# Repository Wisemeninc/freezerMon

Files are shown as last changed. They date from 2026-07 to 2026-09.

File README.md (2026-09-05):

# freezerMon

Cellular monitoring for a mobile cooling unit. A LilyGO **[T-A7608E-H](https://lilygo.cc/products/t-a7608e-h)** (ESP32 + SIMCom A7608E-H LTE Cat-4) reads temperature, door, battery/power-source and GPS, and publishes JSON over **LTE → MQTT**. A self-hosted stack (**Mosquitto → Telegraf → InfluxDB → Grafana**) stores it, draws dashboards, and fires alerts.

```
[DS18B20 x2]──┐
[reed switch]─┤  T-A7608E-H  ──LTE──►  Mosquitto ──► Telegraf ──► InfluxDB ──► Grafana
[battery/VIN]─┘  (deep sleep,                        (MQTT)        (ingest)     (store)     (dash + alerts)
                  offline buffer, GPS)
```

## What the device reports

Two operating regimes: on **battery** the device deep-sleeps between reports (default 5 min; 1 min during alarm/door-open) and wakes instantly on door-open via interrupt. On **external power** it never sleeps — the LTE session stays up, the door is polled every 250 ms (instant alerts), and it reports every 2 min. Payload, retained on `freezer/<id>/telemetry`:

| field | meaning |
|---|---|
| `ts` | unix epoch (from cellular network clock) |
| `t_cab`, `t_amb` | DS18B20 cabinet / ambient °C (second probe optional) |
| `door` | 1 = open (also triggers an instant wake + publish via interrupt) |
| `ext_power` | 1 = running on external power, 0 = on battery |
| `vbat_mv`, `vsolar_mv` | battery / VIN-solar millivolts |
| `rssi_dbm` | LTE signal |
| `lat`, `lon` | GPS fix — **present only when a fix was obtained that wake** (attempted every Nth report to save power). A missing coordinate means "no fix", never a replayed old position; last-known location is whatever the DB holds. |
| `hdop`, `sats` | quality of that fix (horizontal dilution of precision; satellites in view summed over GPS/BeiDou/GLONASS/Galileo) — present with `lat`/`lon`. Fixes are gated: 3D with HDOP ≤ `GPS_MAX_HDOP` (2.5), and the lowest-HDOP sample of a `GPS_SETTLE_S` (10 s) dwell after the first good one; a window that never meets the gate publishes no coordinate. |
| `gps_last`, `gps_last_s`, `gps_last_sats`, `gps_last_svs`, `gps_last_hdop` | outcome of the most recent GNSS hunt, in **every** frame (a hunt runs after the frame, so it describes the previous attempt): 1 = no fix, 2 = fix seen but rejected by the quality gate, 3 = published, 4 = good fix obtained but the follow-up frame could not be sent (it is kept in NVS and backfilled at its own timestamp on a later wake); seconds spent; most satellites in view during the window (fix or not) and their per-constellation split in `+CGNSSINFO` sentence order (this A7608E-H firmware reports three fields — GPS/GLONASS/BeiDou — and no Galileo field); best HDOP seen. `gnss_mode` is the engine's answer to the requested `+CGNSSMODE=15` (all constellations). |
| `vbat_rest_mv`, `vbat_min_mv`, `vbat_sag_ms`, `vbat_sag_at` | supply sag through the modem power-on, sampled at ~500 Hz on the cycles that survive: resting voltage with the modem rail off, the minimum seen, when (ms after rail-on) and in which step (1 cap precharge, 2 rail on, 3 reset pulse, 4 PWRKEY, 5 modem boot). `(rest − min) / ~2 A` ≈ the cell + holder path resistance; brownouts at `ph=1` mean it exceeds ~0.4 Ω. |
| `alarm` | 1 = temp breach active (N consecutive over-threshold samples) |
| `moving` | 1 = unit displaced > `MOVE_ALARM_M` from its parked position (GPS-based) |
| `buffered` | 1 = backfilled sample from an offline gap |
| `wake` | what woke the device: `timer`, `door`, `power_on` |
| `rst` | reset reason (`deepsleep` is healthy; `BROWNOUT` flags a marginal supply) |
| `ph` | how far the *previous* cycle got (NVS breadcrumb, 6 = completed fully) — supply-health forensics |
| `fw` | firmware version — fleet tracking + OTA confirmation |

Alerts (`freezer/<id>/alert`): `temp_breach`, `door_open`, `batt_low`, `moving`, `cold_charge`.

**Cold-charge protection (`cold_charge`)**: Li-ion cells must not be charged below ~0 °C (lithium plating). The board's CN3065 charger has a TEMP protection input, **but it ships wired to GND — disabled** — so the firmware detects the condition instead: if external power is present while the second DS18B20 (`t_amb`, strap it to the cell) reads below `COLD_CHARGE_C` (0 °C), a one-shot `cold_charge` alert fires (re-arms with +2 °C hysteresis) — unplug or warm the cell. This is detection, not enforcement; for autonomous cutoff see [Hardware fix: temperature-protected charging](#hardware-fix-temperature-protected-charging) — the recommended no-solder option is a KSD9700 thermal switch in the charge-input lead. No second probe fitted → the check is inert.

**Movement detection** (GPS-based — the board has no accelerometer): the unit anchors its position while parked; any fix more than `MOVE_ALARM_M` (150 m, above GPS scatter) from the anchor raises a one-shot `moving` alert and switches to **fast reporting (60 s) with a GPS fix every wake**, so the map tracks the unit live. After `MOVE_STOP_CYCLES` consecutive near-still fixes it re-anchors at the new spot and drops back to the normal cadence. Detection latency while parked is bounded by the GPS cadence (a fix every `GPS_EVERY_N_REPORTS` wakes, ~30 min) — a battery-friendly trade-off; wire a vibration sensor to a spare interrupt pin if you need instant wake-on-motion.
No-coverage readings are buffered in RTC memory (24 samples) and backfilled with corrected timestamps on reconnect.

## Hardware & wiring

| Part | Connection |
|---|---|
| DS18B20 probe(s) | data → **GPIO21**, 4.7 kΩ pull-up to 3V3; VCC 3V3; GND |
| Reed switch (door) | between **GPIO32** and **GND** (closed door = closed switch) |
| Battery | 18650 in on-board holder |
| External power | 5 V into the white JST (solar/charger input, 4.4–6 V, ≤500 mA through the CN3065 — the 18650 stays in circuit as the buffer). **`ext_power` sensing needs a 1:2 divider from JST+ to GPIO34** — see [External-power sensing](#external-power-sensing-ext_power-on-gpio34) |
| SIM | nano-SIM, data plan, PIN disabled (or set `SIM_PIN`) |

> Pin map is for the standard T-A7608E-H. Board revisions exist — if the modem won't answer, verify pins against the [LilyGO-T-A76XX](https://github.com/Xinyuan-LilyGO/LilyGO-T-A76XX) `utilities.h` for your exact board.

## Firmware (PlatformIO)

```bash
# ONE-TIME: generate YOUR OTA image-signing keypair (run from the repo root).
# Writes firmware/include/ota_pubkey.h (public, committed) + infra/keys/ (private,
# gitignored). The repo ships a placeholder key you MUST replace — otherwise you
# can't sign updates and your fleet would trust someone else's key.
bun infra/scripts/GenSigningKey.ts

cd firmware
cp include/config.example.h include/config.h   # then edit (see below)
pio run -e t-a7608-tls -t upload               # build + flash over USB (TLS build)
pio device monitor                             # watch the first cycle
```

**`config.h` is gitignored** (it holds credentials); the committed **`config.example.h`** is the template — copy it and replace every placeholder value:

| Setting | What to put |
|---|---|
| `DEVICE_ID` | **seed** default name only — the live name is stored in NVS and set per-unit at runtime via the `/setname` console (survives OTA). One firmware image serves a whole fleet; leave `""` to auto-derive a unique `cooler-<chipid>` on first boot. |
| `APN` (+ `GPRS_USER`/`GPRS_PASS`, `SIM_PIN`) | from your SIM carrier — MVNOs often need user/pass |
| `MQTT_HOST` / `MQTT_HOST_IP` / `MQTT_USER` / `MQTT_PASS` | your broker + the credentials you created in `mosquitto_passwd` |
| `OTA_MANIFEST_URL` | your fw host + the `OTA_PATH_TOKEN` from the server `.env` |
| `DEBUG_AP_PASSWORD` | WPA2 password for the on-device console AP — **unique + high-entropy per unit** |

Notes:
- Uses the **lewisxhe TinyGSM fork** (declared in `platformio.ini`) — stock TinyGSM has no A76XX support.
- APN: ask your carrier; MVNOs often need `GPRS_USER`/`GPRS_PASS`.
- Sleep is guaranteed: a 3-minute awake guard forces deep sleep even if LTE hangs (an OTA pull suspends it, but has its own 15-minute cap).

## Platform (any Docker host / VPS)

```bash
cd infra
cp .env.example .env        # fill every value (openssl rand -hex 24 for tokens)

# create the three MQTT identities (values from .env). Each is confined to its own
# topics by mosquitto/config/acl: devices write telemetry/alert + read cmd,
# telegraf is read-only, publisher may only write cmd (OTA). Never share one.
docker run --rm -v ./mosquitto/config:/cfg eclipse-mosquitto:2.0 sh -c '
  mosquitto_passwd -c -b /cfg/passwd freezer   "<MQTT_PASSWORD>" &&
  mosquitto_passwd    -b /cfg/passwd telegraf  "<TELEGRAF_MQTT_PASSWORD>" &&
  mosquitto_passwd    -b /cfg/passwd publisher "<PUBLISHER_MQTT_PASSWORD>"'

# the file is created root-owned; the broker drops privileges and must be able to read it:
docker run --rm -v ./mosquitto/config:/cfg eclipse-mosquitto:2.0 \
  sh -c 'chown mosquitto:mosquitto /cfg/passwd && chmod 640 /cfg/passwd'

docker compose up -d

# scope the InfluxDB access (the admin token must not live in Telegraf or Grafana):
B=$(docker exec freezermon-influxdb-1 influx bucket list --name telemetry --hide-headers | cut -f1)
docker exec freezermon-influxdb-1 influx auth create --org freezermon --write-bucket "$B" --description telegraf-write   # -> TELEGRAF_INFLUX_TOKEN
docker exec freezermon-influxdb-1 influx auth create --org freezermon --read-bucket  "$B" --description grafana-read     # -> GRAFANA_INFLUX_TOKEN
# put both in .env, then: docker compose up -d telegraf grafana
```

Grafana: `http://<host>:3000` → **FreezerMon** folder → dashboard shows temperature, power source, door, battery, signal, and a location map. Firewall: expose only **8883** (devices, TLS — via Traefik or the `mosquitto.conf` TLS listener) and **3000** (you) — plaintext 1883 is bound to localhost and InfluxDB stays internal. The firmware's default build env is TLS; the plain env + `MQTT_PORT 1883` is for LAN-only bring-up.

### Logins

Two accounts, created like this:

| login | role | purpose |
|---|---|---|
| `admin` | Admin | you — full control (password: `GRAFANA_ADMIN_PASSWORD`) |
| `operator` | Viewer | read-only dashboards for whoever runs the unit (password: `GRAFANA_OPERATOR_PASSWORD`) |

```bash
cd infra && set -a && source .env && set +a && bun scripts/CreateOperator.ts
```

## Alerting

Four rules are provisioned: cabinet temp above 8 °C for 10 min (cooler food-safety ceiling — set it *above* your unit's normal band and keep it in sync with `TEMP_ALARM_C` in `config.h`, or the alarm never clears and the fast reporting cadence drains the battery ~5×; a freezer would use e.g. −12), no data for 15 min (offline/out of coverage), battery under 3.4 V, and cabinet probe missing (the unit reports but carries no `t_cab` for 15 min). The temperature, battery and probe rules judge the unit's **last known reading** (30-day lookback), not "a reading in the last N minutes": a unit that goes silent while in alarm stays in alarm — the reminder then says how old the reading is — and only a fresh reading on the right side of the limit produces the "OK again". Silence itself is reported once by the offline rule.

A unit that has been silent for **more than a day** gets no further messages at all — no 4-hourly reminders, no "OK again" — until it reports again (the offline message at 15 min already told you it went quiet). The relay does the muting from a `last_report_age_s` annotation every rule carries, so Grafana's own alert state is untouched. Tune or disable with `MUTE_AFTER_SILENT_S` in `.env` (seconds, default 86400, `0` = never mute); the relay logs every muted message.
**Delivery is Signal**, no phone-number registration needed: the stack ships `signal-cli-rest-api` plus a tiny relay, and Grafana's provisioned contact point posts to the relay. One-time setup:

```bash
# 1. fill SIGNAL_NUMBER (your own number) and SIGNAL_RECIPIENTS in .env, then
docker compose up -d signal alert-relay && docker compose restart grafana
# 2. link the container as a secondary device of YOUR Signal account (like Signal Desktop):
#    on your PC:  ssh -L 8080:127.0.0.1:8080 <server>   then open
#    http://localhost:8080/v1/qrcodelink?device_name=freezermon   and scan it in Signal
#    (Settings -> Linked devices -> +). Messages then come from your own account.
# 3. test:
docker compose exec alert-relay wget -qO- http://localhost:8091/test
```

Every rule change (firing and resolved) arrives as one short message: `🔴 ALARM: Cabinet temperature high — cooler-01`. To notify a group instead of a person, put the group id (from `GET /v1/groups/<number>` on the API) in `SIGNAL_RECIPIENTS`. If you prefer Telegram or email, replace the contact point in `infra/grafana/provisioning/alerting/contactpoints.yml`.

## Field debugging (WiFi console)

The device broadcasts its own WiFi access point — `freezermon-<DEVICE_ID>`, password `DEBUG_AP_PASSWORD` from `config.h` (change the default!) — for on-site debugging with no cellular dependency:

- **After a cold boot** (power-on/reset): console stays up for `DEBUG_AP_WINDOW_S` (default 2 min) before the first deep sleep — connect while installing.
- **On external power**: console is always available.
- **On battery timer/door wakes**: WiFi stays off — zero power cost in normal operation.

Connect to the AP, then: `http://192.168.4.1/status` (live readings + state, JSON), `http://192.168.4.1/log` (recent event log: boot reason, LTE attach attempts, MQTT results, GPS, sleep decisions), `http://192.168.4.1/sms` (SMS inbox — read SIM activation/confirmation texts without a phone), and `http://192.168.4.1/setname` (name this unit). WiFi is never used for telemetry — LTE remains the only transport.

**Naming a unit.** `/setname` writes the device name to NVS, which is what drives the MQTT topics (`freezer/<name>/…`) and the InfluxDB `device` tag Grafana filters on. Because NVS survives OTA (only the app partition is rewritten), the name sticks across updates — so the deployment workflow for a fleet is: flash the *same* image to every unit, then give each one a unique name here. Valid names are lowercase letters, digits, and hyphens (1–21 chars — bounded so the `freezermon-<name>` AP SSID stays within the 32-char WiFi limit); setting one reboots the unit so every topic re-derives cleanly. Leaving `DEVICE_ID` blank in `config.h` auto-derives a unique `cooler-<chipid>` per unit.

### OTA updates

Updates are **cryptographically signed**: the device installs an image only if its RSA-2048/SHA-256 signature — taken over the **version + image**, so downgrades and tampering both fail — verifies against the public key baked in at build time. This holds even though the command and download channels aren't themselves authenticated. Model + threat analysis: [docs/HARDENING.md](docs/HARDENING.md); the (long) road to a reliable pull on this modem: [docs/OTA-INVESTIGATION.md](docs/OTA-INVESTIGATION.md).

**Over LTE (primary)** — no site visit at all:

```bash
# 1. bump FW_VERSION in firmware/src/main.cpp, build:
pio run -e t-a7608-tls
# 2. sign + split + publish (also sets the retained MQTT command):
bun infra/scripts/PublishFirmware.ts 2.54 cooler-01
```

`PublishFirmware.ts` signs the image, splits it into overlapping ~32 KB pieces (the A7608's HTTP stack can't hand back a ~900 KB response in one go — see the investigation doc), and sets a retained command on `freezer/<id>/cmd`. After each report the device compares `ota_ver`; if it's **strictly newer** (anti-rollback) it pulls the pieces over plain HTTP, reassembles and hashes them, verifies the signature, installs into the inactive OTA slot, and reboots — the next telemetry's `fw` field confirms it. Guard-rails: on battery it updates only above `OTA_MIN_VBAT_MV` (default 3.7 V), the watchdog stays fed, per-piece retries ride out cellular blips, and a bad / interrupted / unsigned image leaves the running firmware untouched. Data cost: ~1 MB per update.

**Over the debug WiFi (fallback)** — `http://192.168.4.1/update`: upload `firmware.bin` **and** `firmware.bin.sig` plus the version; it installs only if the signature verifies. Same dual-slot safety. (This is the trusted channel to establish the *first* signed build on a fleet — see HARDENING.md.)

### OTA download internals (piece-split + verification)

Getting a ~900 KB image through the A7608 reliably was the hard part. The modem's HTTP stack can't hand back a large response in one transfer:

- its HTTP response cache is only ~57 KB, so a single GET larger than that can't be read back in full;
- it **drops the last ~3072 bytes of every cached response** — it reports the full `Content-Length` in `+HTTPACTION` but only caches `length − 3072`, then `ERROR`s;
- it won't cache `206 Partial Content`, so ranged GETs come back with a 0-byte body;
- and streaming over the CCH TCP channel wedges at ~344 KB.

**Solution — split the image into small, overlapping packages.** `PublishFirmware.ts` slices `firmware.bin` server-side:

```
PIECE   = 32768                 # bytes per piece file (comfortably under the cache)
OVERLAP = 4096                  # > the 3072-byte tail-drop
STEP    = PIECE - OVERLAP        # = 28672 real bytes each piece contributes
piece_i = image[i*STEP : i*STEP + PIECE]        # firmware.bin.000, .001, …
```

Because pieces advance by `STEP` but span `PIECE`, consecutive pieces **overlap** by `OVERLAP`; the short final piece is zero-padded by `OVERLAP`. The device fetches each piece as a plain `200` GET (fits the cache), then reads only the **deliverable prefix** `want = min(plen − ota_skip, remaining)`. Since `ota_skip = OVERLAP = 4096 > 3072`, that read never reaches the dropped tail, and the prefixes tile the image with **no gap and no overlap in the written bytes** — sum of `want` over all pieces = `ota_size` exactly. (`ota_skip` travels in the retained command, so the overlap is tunable without a reflash.)

Two more device-side rules make it robust on cellular:

- **Read each piece from offset 0 into a RAM buffer, commit only on a clean read.** The modem's offset-resume after a re-fetch returns *wrong bytes*, so a mid-piece resume corrupts the image (byte count still reaches 100 %); we never resume — a failed read re-fetches and re-reads the whole piece from 0, up to `MAX_TRIES = 10`, which absorbs transient blips.
- Only after a piece reads cleanly is it `Update.write()`-n to the inactive OTA slot.

**Verification — nothing installs unchecked.** While the assembled bytes are written, the device maintains two running digests:

- a streaming **MD5** (`Update.setMD5`) — a cheap corruption pre-check, and
- a streaming **SHA-256** over `version ‖ 0x00 ‖ image`.

When the image is complete it fetches `firmware.bin.sig` (a 256-byte **RSA-2048** signature, padded past the tail-drop and read back the same way) and verifies it against the public key compiled into firmware (`mbedtls_pk_verify`, PKCS#1 v1.5 / SHA-256). The install gate is a single short-circuit:

```c
if (ok && done >= total && otaVerifySig(url, digest) && Update.end(true)) { /* reboot */ }
else Update.abort();
```

`Update.end(true)` — which sets the boot partition — runs **only** after the signature verifies over the digest, and only when the offered version is strictly newer (`verNewer`, anti-rollback). A truncated, corrupt, unsigned, tampered, or downgraded image is aborted and the running firmware is left untouched. Full derivation of the 3072-byte tail-drop and the dead ends that preceded this: [docs/OTA-INVESTIGATION.md](docs/OTA-INVESTIGATION.md).

## Data usage (fits easily in a 5 GB plan)

| Regime | Per report | Monthly |
|---|---|---|
| Battery, 5-min cadence, plain MQTT | ~2–3 KB (fresh TCP+MQTT session each wake) | ~25–30 MB |
| Battery, 5-min cadence, TLS | ~8 KB (handshake each wake) | ~70–90 MB |
| External power, 2-min cadence | ~0.5 KB (persistent session) | ~15 MB |

GPS itself is received, not transmitted. **Assisted GNSS** (`AT+CAGPS`) downloads a few KB of ephemeris at most every ~2 h (`AGPS_REFRESH_S`) so cold fixes land in seconds instead of timing out — a small, bounded cost. Worst case (TLS on battery) still uses **under 2 %** of a 5 GB monthly allowance; a 5 GB plan gives ~50× headroom.

## Security

Full model and the independent-review findings are in [docs/HARDENING.md](docs/HARDENING.md). In brief:

- **Signed OTA** is the primary control: every image is RSA-2048/SHA-256 signed and verified on-device (with the version bound in, for anti-rollback) before install — over both LTE *and* the WiFi `/update` form. So even though the MQTT command channel isn't broker-authenticated (the modem's TLS runs `authmode=0`), a MITM can't push forged, tampered, or downgraded firmware. **Generate your own signing key first:** `bun infra/scripts/GenSigningKey.ts` (the committed `ota_pubkey.h` is a placeholder).
- Broker requires authentication **and authorization**: `mosquitto/config/acl` confines every identity to its own topics (per-device users via `pattern … %u`; the shared device credential can never write a `cmd` topic; Telegraf is read-only; `PublishFirmware.ts` uses a `publisher` identity that can only write `cmd`). A leaked device credential therefore cannot arm an OTA. Until per-device credentials land (HARDENING P3) the shared `freezer` identity can still write any unit's `telemetry`/`alert` topics — forging readings, and thereby clearing a breach alert, remains possible for whoever holds it — and, because each device subscribes to its own retained frame as delivery proof, the shared identity can also *read* every unit's telemetry, coordinates included. The stack refuses to start with unset secrets (`${VAR:?}`). The committed default is **plaintext 1883** (the `8883` listener is a commented upgrade path in `mosquitto.conf`, and `platformio.ini`'s default env is the non-TLS build) — for anything Internet-facing, enable 8883 and build `t-a7608-tls`; the fork's secure client encrypts but doesn't validate the broker cert by default, so signed-OTA is what guarantees firmware integrity regardless; for full MQTT MITM protection, load a CA cert via the modem's certificate store.
- **The firmware image contains the compiled-in secrets** (`MQTT_PASS`, `DEBUG_AP_PASSWORD`, APN) and the OTA pieces are fetched over plain HTTP behind `OTA_PATH_TOKEN`. Anyone who learns the token (on-path observer of one OTA, or a MITM of the unauthenticated MQTT session) can reassemble the pieces and read those secrets — so treat the token as a bearer secret, and treat the credentials in the image as *remotely* exposed until per-device NVS-provisioned credentials land (HARDENING P3). `PublishFirmware.ts` no longer leaves the unsplit `firmware.bin` in the served directory.
- Cellular OTA is **bounded**: one pull is capped at `MAX_OTA_MS` (15 min) and a version that has failed `OTA_MAX_FAILS` (3) times is refused until a different version is commanded — a retained `cmd` pointing at a broken image costs three bounded attempts, not the battery.
- `config.h`, `.env`, and `infra/keys/` (the OTA **private** signing key) are gitignored; only `.example` templates and the **public** key are committed.
- Known follow-ups (see HARDENING.md): per-device credentials, and a unique high-entropy `DEBUG_AP_PASSWORD` per unit.

## Power expectations

Deep sleep with the modem fully off dominates the budget. At a 5-min cadence expect roughly 2–4 weeks on a single 18650 (LTE attach ≈ 10–30 s at ~100+ mA per cycle is the main cost; GPS every 6th cycle). On external power the unit simply reports faster.

### External-power sensing (`ext_power`) on GPIO34

The firmware decides between the two regimes with one ADC reading: `ext_power = (GPIO34 × 2) ≥ 4400 mV` (`EXT_POWER_MIN_MV`). It assumes GPIO34 sits **behind a 1:2 divider on the VIN/solar net**, as on the T-A7608X **v1.1/V2** boards (LilyGO's `utilities.h`: *"only version v1.1 or V2 has solar adc pin"*).

**On the T-A7608E-H with the soldered 18650 holder (V1.0 schematic) that divider does not exist** — GPIO34 is a bare header pin. 5 V on the white JST lights the charge LED and charges the cell, but GPIO34 floats at ~0.3 V, `ext_power` never goes to 1, and the unit keeps deep-sleeping on the battery cadence. Verified the hard way (2026-08-26): a year of telemetry with a lit charge LED and `vsolar_mv` never above noise.

**Permanent fix — two resistors:**

```
JST VIN(+) ──[100 kΩ]──┬──[100 kΩ]── GND
                       └── GPIO34 (header pin 34)
```

5 V → 2.5 V at the pin → firmware reads ~5000 mV → `ext_power=1`. Any matched pair from 47 kΩ to 220 kΩ works (25 µA at 100 k). Feeding the divider from the JST rather than USB keeps `vbat_mv` readable (the board can't read the cell while on USB) and keeps the 18650 in circuit as the buffer for the modem's 2 A bursts — the JST path is capped at the CN3065's 500 mA.

**Bench test without resistors (variable PSU):** set the PSU to **2.5 V** with its current limit at the minimum *before* connecting, then PSU− → board GND, PSU+ → GPIO34. Anything from 2.2–3.0 V registers; the next wake publishes `vsolar_mv ≈ 5000`, `ext_power=1`, and the unit switches to the powered regime (no sleep, 120 s cadence, debug AP stays up). Caveats: **never put 5 V on GPIO34** (3.3 V pin, 3.6 V absolute max — 3.3 V from a PSU that overshoots is a dead pin, and it reads no better than 2.5 V); and with the PSU on the pin nothing is charging the cell while the firmware stops sleeping (~170 mA) — a ten-minute test, not a state to leave.

### The 18650: voltage ladder

What the firmware does as `vbat_mv` falls:

| vbat | Behaviour |
|---|---|
| ~4200–3700 mV | Normal operation |
| < 3700 mV (`OTA_MIN_VBAT_MV`) | OTA installs **deferred** (no flash writes on a sagging supply); telemetry unaffected |
| < 3400 mV (`BATT_LOW_MV`) | `batt_low` alert on every report + the Grafana battery rule fires — recharge now |
| ~3300–3400 mV *under load* | Modem TX bursts sag the rail → **brownout resets** (see below); reporting gets ragged and lossy |
| ~2500–3000 mV | Cell protection (or the ESP32's own brownout detector) cuts — unit is silent; the Grafana *no-data-15-min* rule is your notification |

### Brownouts on battery (cold or tired cells)

The A7608's LTE bursts peak around **2 A**. A cold 18650 (this is a *cooling* unit — a cell living in the cold zone at 2–5 °C has markedly higher internal resistance) or a worn one can sag below the ESP32's brownout threshold under those bursts **even when its resting voltage looks healthy (4+ V)**. Symptoms, from mildest to worst:

- `/log` shows `reset=BROWNOUT` on boot lines;
- telemetry frames arrive with `wake:"power_on"` and `boot:1` **every time** — RTC memory is wiped each reset, so nothing survives between cycles: the boot counter, the temp-alarm breach streak (the alarm can never trigger), the movement anchor, and the offline buffer are all lost each wake;
- cycles die before publishing at all (irregular gaps in the data).

**The firmware stays fully functional on a marginal supply** (learned the hard way — the failure mode is a *double boot per wake*: the first modem power-on's inrush browns the cell out, the reboot's second attempt survives on the precharged caps). Defenses, all breadcrumb-driven:

- NVS **phase breadcrumbs** record how far each cycle got; telemetry carries `rst` (reset reason) and `ph` (previous cycle's last phase) so the pattern is visible remotely.
- On a `BROWNOUT` boot the **debug AP is shed**; **GNSS is shed only if the previous cycle died under RF load** (`ph` 2–5) — a wake-inrush double boot (`ph` 1/6) keeps GPS, since its attach already proved the cell carries the RF load.
- The **temp-alarm streak, movement anchor, queued alerts and AGPS age are NVS-mirrored** (write-on-change), so alarms, movement detection and alert delivery all work even when RTC is wiped every wake.
- **AGPS assistance is re-downloaded per modem power cycle** — it lives in the GNSS engine's RAM and dies with the modem rail, so wall-clock caching would silently kill fixes on battery.

Net effect: on a supply that browns out at every wake the unit still publishes, sleeps, alarms, tracks movement and delivers GPS — the hardware mitigations below restore efficiency, not functionality.

Hardware mitigations, in order of effectiveness:

1. **Bulk capacitance across the battery input** — solder a **1000–2200 µF low-ESR electrolytic** (≥6.3 V; a 105 °C-rated part behaves better in the cold) directly across the 18650 holder pads. This is the classic SIMCom-board fix: it carries the millisecond-scale TX/inrush spikes that trigger most brownouts. It can *not* carry the multi-second attach current — if the cell sags under sustained load, capacitance only delays the reset (that league needs a ~1 F low-ESR supercap/LIC).
2. **Keep the cell out of the cold zone.** The DS18B20 probe is on a wire — mount the board + battery outside the cooler and only the probe inside. Removes the root cause.
3. **External power** where the unit rides in a vehicle anyway (also gives instant door alerts and faster reporting).
4. A healthy, genuine cell: high-drain rated (≥5 A), not an aged or counterfeit one.

Related: the board browns out on a PC USB port at power-on regardless of battery temperature — it needs a **≥2 A** supply or the 18650 for the modem's startup surge.

### Hardware fix: temperature-protected charging

> ⚠️ **Disclaimer:** the hardware options below (charge gating, heaters, thermal fuses) are a record of **one specific build — not a recommendation or professional advice**. Li-ion batteries and heating elements are safety-critical: component values, setpoints and power figures here apply to *this* enclosure, cell, climate and supply, and reviews/datasheets vary between suppliers. **Do your own calculations, read the actual datasheets of the parts you buy, and verify thermal behavior on the bench before deploying.** You assume all risk (see [LICENSE](LICENSE) — the software and this documentation come with no warranty of any kind).

Li-ion cells must never be **charged below ~0 °C** (lithium plating → permanent capacity loss, eventual safety risk). The board's charger — a **CN3065** ([datasheet](https://raw.githubusercontent.com/SeeedDocument/Lipo_Rider_Pro/master/res/DSE-CN3065.pdf)) — has exactly the protection input needed: the **TEMP pin suspends charging whenever V(TEMP) < 46 % of VIN** and resumes automatically above it. But on this board **TEMP (pin 1) is wired straight to GND, which disables the function** — verified in the [T-A7608X schematic](https://github.com/Xinyuan-LilyGO/LilyGO-T-A76XX/blob/main/schematic/esp32/T-A7608X-V1.0.pdf) (page 3, charger block `U7`).

#### Option A (recommended — no board soldering): thermal switch in the charge input

Splice a **KSD9700-type bimetal thermal switch** into the 5 V supply lead (USB/solar → board VIN) and thermally bond the switch to the **18650 cell** (not the air):

```
USB / solar 5 V ──[ KSD9700 NO 15 °C on the cell — re-opens above 0 °C on falling temp ]──► board VIN
18650 ───────────────(directly in its holder, unswitched)──► board
```

- Cold cell → switch opens → the CN3065 has no input → **charging physically impossible**; the battery keeps powering the device uninterrupted (discharging in the cold is allowed — and is what keeps the monitor alive).
- Warm again → power returns by itself. Fully autonomous: works even if the firmware is dead — the right property for a safety function.
- Part: **normally-open, action point ~15 °C** (KSD9700 is sold in both polarities and many setpoints), rated ≥ 1 A. **The setpoint must be chosen for the *re-opening* (falling-temperature) edge, not the closing one**: these discs re-open 10–20 K *below* their action point, so an NO +5 °C part would keep charging enabled down to roughly −5…−15 °C — violating the 0 °C hard limit. `T_action − ΔT_return ≥ 0 °C` → with typical hysteresis, ~15 °C action is the minimum safe choice (check the return differential on the datasheet of the part you actually buy).
- Trade-off: while cold, *external power* is gone too (charge and load share the VIN path) — the unit simply runs its normal battery regime.

> ⚠️ **Do NOT put the switch between the battery and the board.** That kills the whole monitor whenever the cell is cold (it's charging that's forbidden, not discharging), and its contact resistance sits in series with the modem's 2 A bursts — the exact path where marginal resistance causes the brownout loop described above.

#### Option B (board-level, delicate): re-enable the CN3065's own TEMP protection

Only if you're comfortable lifting an SMD pin — re-enable the chip's protection as a **cold cutoff**:

1. **Lift TEMP (pin 1) of the CN3065** off its GND pad (fine iron or hot air — this is the only delicate step), or cut its trace to GND.
2. Wire this divider, with the **NTC strapped to the 18650 cell** (not the air):

```
  CN3065 VIN (5 V / solar side)
        │
     [ NTC 10 kΩ B3950 ]   ← thermally bonded to the cell
        │
        ├──────── TEMP (pin 1, lifted from GND)
        │
     [ R1 22 kΩ ]
        │
       GND
```

3. How it behaves: cold cell → NTC resistance rises → V(TEMP) falls below 46 %·VIN → **charging suspends**; the cell warms → resumes on its own. With 10 k B3950 + 22 k, the cutoff lands at ≈ **+1 °C**. The divider is ratiometric to VIN, so it stays correct as a solar input sags and recovers. Tune R1 for a different cutoff: `R1 = R_NTC(at cutoff) × 0.46/0.54`.

Notes: in this orientation the single threshold guards the **cold** end only (the stock hot-side protection was disabled anyway); pair it with the firmware `cold_charge` alert for visibility. If SMD pin-lifting isn't your thing, the no-surgery alternative is an inline charger module with its own NTC input ahead of the board, or simply keeping the cell out of sub-zero placement.

#### Option C (installed units): heated battery compartment + dual thermal switches

For a permanently installed unit on a wired 5 V supply, extend Option A into a fully self-managing thermal envelope — **~€2 of bimetal discs, zero code, works even if the firmware is dead**:

```
                       ┌─[ KSD9700 NC 25 °C ]──[ thermal fuse 70 °C ]──► 2× PI film heater (12 V 7 W rated,
wired 5 V supply ──────┤       (on the cell)        (cell side)           parallel at 5 V ≈ 2.4 W, in the box)
                       └─[ KSD9700 NO 15 °C ]──► board VIN (charge input)
18650 ────────(unswitched, in its holder)──────► board
```

Both discs are **thermally bonded to the cell**. Behaviour: compartment cold → heater on, charging blocked; warming past ~15 °C → charging resumes; past ~25 °C → heater off (re-closes ~10–15 °C lower, so the compartment cycles roughly 10–25 °C). The cycle repeats as ambient demands — battery stays in its safe charge window through a freezing winter, autonomously. (The 15 °C gate is not merely what's stocked — it's required: the gate's protection edge is its *re-opening on falling temperature*, 10–20 K below the action point, so a lower-setpoint NO disc would keep charging enabled below 0 °C. See Option A's part note.)

Build rules:

- **Heater from external 5 V only, never the battery** — heating the cell from the cell drains it *and* puts a sustained load on a cold, high-IR cell (the brownout recipe). Wired to the supply, heat exists exactly when charging is possible — which is exactly when the cell must be warm.
- **Heater element — buy 12 V films and run them at 5 V.** Two **12 V 7 W polyimide (Kapton) film heaters** (25×50 mm, adhesive-backed) **in parallel on the 5 V rail** deliver ≈ 2.4 W total — power scales with V², so each film runs at ~17 % of rating. This is the safest possible configuration: a derated film is **burn-proof by physics** (≈ 25–30 K max rise, even free-standing), whereas a film *rated* for your drive voltage runs at full power and can pass 100 °C at a hotspot during a cold start (owner reviews measure ~180 °C on these films at rated voltage) — the cell-mounted KSD controls *duty cycle*, not film surface temperature. If you do use a rated-voltage film (e.g. 5 V 3 W at 5 V): bond it flat to a metal spreader/holder (thermal mass caps the hotspot), no air-gapped corners, and move the fuse **onto the film** (72–77 °C). A film heater is plain resistive — **not self-limiting** — which is why the thermal fuse below is mandatory either way; a self-limiting PTC plate is an acceptable alternative that earns its fuse for free. And never move the heater branch to a vehicle's 12 V rail — at rated voltage next to a Li-ion cell it's a genuine fire hazard.
- **One-shot thermal fuse (RY-type, 65–70 °C) in series with the heater, mounted cell-side** — the fail-safe for the one runaway scenario: KSD contacts welding shut. 65–70 °C by the cell pops before the cell reaches harm territory (cells must never exceed ~60 °C, nor charge above 45 °C); with the derated films the normal peak is ~45–55 °C, so ~15 K of nuisance margin remains. If you mount the fuse directly on a film's hotspot instead, use 72–77 °C to avoid nuisance trips. **Crimp the fuse leads, don't solder** (or heat-sink the lead with pliers while soldering) — the element is a low-melting alloy and soldering heat kills more of these than service does.
- **Sensor placement is the control design**: the **KSD disc goes on the cell** (the variable being regulated), *not* on the heater — mounted on the film it would open seconds after power-on, regulating the heater's own skin at 15 °C while the cell stays frozen. The fuse is the component that lives at the heater. Disc = regulation, fuse = runaway; don't swap their homes.
- **Heater taps the 5 V *upstream* of the charge-cutoff switch** (as drawn) — downstream, it would lose power exactly when it's needed.
- **Mind the KSD9700 hysteresis**: these discs re-close 5–15 °C below their open point, so a 10 °C NC part may not re-close until ~0 °C. Pick **15–20 °C NC** for the heater so the band stays comfortably above freezing.
- **Supply sizing: 5 V / ≥12 W (2.4 A)**, wired in with a short run (≤10 cm is negligible drop). Sustained worst case ≈ charge (~1 A) + heater (~0.5 A) + board (~0.3 A) ≈ 1.8 A; the modem's 2 A TX bursts ride on the battery+caps, so the PSU only carries the average. Long thin leads are the hidden killer at these currents — 0.3 Ω of cable drops 0.6 V under burst.
- **Regime note**: a supply wired into VIN drives the `ext_power` sense, so the powered regime engages (no deep sleep, 250 ms door polling, 2-min reports, console always on). When the cold-gate opens VIN, the unit falls back to the battery deep-sleep regime until the heater restores the compartment — expect the reporting cadence to shift with compartment temperature in deep winter. (A micro-USB supply does *not* trigger `ext_power` — it feeds VBUS, bypassing the sense; use VIN for installed units.)

Parts list (everything under ~€10 total):

| Part | Spec | Role |
|---|---|---|
| PSU | 5 V / ≥12 W (2.4 A), wired to VIN, run ≤10 cm | powers board + charging + heater |
| KSD9700 **NC 25 °C** | bimetal disc, ≥1 A, bonded to the cell | heater thermostat (on below ~25 °C, re-closes ~10–15 °C lower) |
| KSD9700 **NO 15 °C** | bimetal disc, ≥1 A, bonded to the cell | charge gate (blocks VIN below ~15 °C — errs safe vs the 0 °C limit) |
| PI film heater ×2 | **12 V 7 W rated**, ~25×50 mm, adhesive — wired **in parallel at 5 V** ≈ 2.4 W | heat source, burn-proof via derating (never feed these 12 V) |
| Thermal fuse | **65–70 °C**, one-shot, crimped, cell-side | fail-safe if the heater disc welds shut |
| Insulation | a few mm of foam around the battery box | makes 3 W enough for deep winter |

## Production deployment (Traefik)

To run it behind Traefik on a public host, use `infra/docker-compose.traefik.yml` and set **your own** domains in the router rules (the file ships `example.com` placeholders): e.g. one host for Grafana + the OTA `/fw/` path, and one for MQTT-over-TLS on the `mqtts` entrypoint — Traefik terminates TLS, with certs via Let's Encrypt once DNS points at the host. Keep secrets in the server's `.env`. Device config for production: `MQTT_HOST` = your MQTT domain, `MQTT_PORT 8883`, flash env `t-a7608-tls`.

## License

[MIT](LICENSE) © 2026 Peter Hamborg Haugaard.

Third-party components keep their own licenses — see [THIRD-PARTY-NOTICES.md](THIRD-PARTY-NOTICES.md). Note the firmware links **TinyGSM (LGPL-3.0)** and the **Arduino-ESP32 core (LGPL-2.1)**: weak copyleft, satisfied here because the full source is public and rebuildable.

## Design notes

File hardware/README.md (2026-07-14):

# DIN-rail mount — LilyGO T-A7608E-H

Two-piece, support-free FDM print (designed for Bambu Lab, works on any printer).
Source: `DinRailMount.scad` (parametric OpenSCAD). Ready-to-slice: `TrayT-A7608.stl`, `DinClipTS35.stl`.

Board dimensions are taken from LilyGO's official drawing (`T-A7608X-ESP32.dxf`):
PCB 33.07 × 110.54 mm, M3 corner holes on a 27.72 × 105.59 mm grid — the standoffs
land exactly on them.

## Parts

| Part | File | Print orientation |
|---|---|---|
| Board cradle | `TrayT-A7608.stl` | as exported (floor on bed, standoffs up) |
| TS35 DIN clip | `DinClipTS35.stl` | as exported (channel up) |

The 22 mm standoffs leave the 18650 holder on the PCB back hanging free above
the tray floor; airflow windows sit under the battery and modem zones.

## Rail orientation (horizontal *or* vertical)

The tray floor carries a **4-boss cross**, so one printed tray + clip mounts the
unit either way on the rail — no reprint, no second part:

- **Horizontal** (landscape): bolt the clip on straight. Board long axis runs
  *along* the rail.
- **Vertical** (portrait): bolt the same clip on turned **90°**; its two screws
  pick up the other boss pair. Board long axis runs *across* the rail (vertical).

Set `mount = "horizontal"` / `"vertical"` in the SCAD only if you want the
`part="both"` assembly preview to match — it does not change the printed parts.

## Print settings

- **Material:** PETG (cold-room duty; PLA gets brittle below 0 °C)
- Layer 0.2 mm, 4 perimeters, 40 % infill on the clip (strength in the spring arm), 15 %+ on the tray
- No supports, no brim needed (add a brim on the clip if your PETG warps)

## Hardware

- 4 × M3×6 self-tapping (board → standoff pilot holes, Ø2.7)
- 2 × M3×10 countersunk self-tapping (clip → tray floor bosses)

## Assembly

1. Screw the board onto the four standoffs (18650 holder facing down into the tray).
2. Screw the clip to the tray floor through **one** boss pair — straight for a
   horizontal (landscape) hang, or turned 90° onto the other pair for a vertical
   (portrait) hang. The screw heads sit inside the rail channel — keep them flush.
   (The unused pair stays open; it just adds a little ventilation.)
3. On the rail: hook the **fixed edge** (the side without the tab) over the top
   lip of the TS35 rail, then press the bottom down until the spring latch snaps
   over the lower lip. To release, pull the tab outward (or lever a flat
   screwdriver under it) and tilt the unit off.
4. Route antenna pigtails / DS18B20 / reed-switch cables through the open ends;
   zip-tie slots in the floor edges take 3.6 mm ties for strain relief.

## Tuning (edit `DinRailMount.scad`, re-export)

| Symptom | Parameter |
|---|---|
| Board tight/loose in skirt | `clearance` (default 0.6/side) |
| Clip tight/loose on rail | `rail_fit` (default 0.4) |
| Latch too stiff / too weak | `lip_t` engagement, slot geometry in `clip()` |
| Taller battery/underside parts | `standoff_h` (default 22) |

Re-export:

```
openscad -o TrayT-A7608.stl  -D 'part="tray"' DinRailMount.scad
openscad -o DinClipTS35.stl -D 'part="clip"' DinRailMount.scad
```

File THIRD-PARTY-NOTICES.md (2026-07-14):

# Third-party notices

freezerMon itself is licensed under the [MIT License](LICENSE). It builds on the
components below, which remain under their own licenses. Nothing here changes the
license of your own code, but note the **LGPL** items when you distribute the
compiled firmware.

## Firmware (compiled into `firmware.bin` and distributed via OTA)

| Component | License | Notes |
|---|---|---|
| [TinyGSM](https://github.com/vshymanskyy/TinyGSM) (lewisxhe A76XX fork) | **LGPL-3.0** | Weak copyleft. You may combine it with MIT-licensed code, but recipients of the firmware binary must be able to relink/replace TinyGSM — satisfied here because the full source is public and rebuildable with PlatformIO. |
| [Arduino-ESP32 core](https://github.com/espressif/arduino-esp32) | LGPL-2.1 + Apache-2.0 | Same weak-copyleft note as above (the framework). |
| [PubSubClient](https://github.com/knolleary/pubsubclient) | MIT | |
| [DallasTemperature](https://github.com/milesburton/Arduino-Temperature-Control-Library) | MIT | |
| [ArduinoJson](https://github.com/bblanchon/ArduinoJson) | MIT | |
| [OneWire](https://github.com/PaulStoffregen/OneWire) | Permissive (grant in source headers; no standalone SPDX license file) | Widely used; review the header terms for strict compliance. |
| Mbed TLS (via ESP-IDF) | Apache-2.0 | Used for the OTA image-signature verification. |

**LGPL compliance:** because this repository publishes complete, buildable source
for the firmware, anyone who receives a `firmware.bin` can rebuild it (optionally
with a modified TinyGSM), which satisfies the LGPL relinking requirement. Keep the
source public/available if you distribute binaries.

## Platform services (run as-is via Docker — not linked into freezerMon's code)

These are used unmodified as network services; their licenses do not propagate to
freezerMon's code.

| Service | License | Notes |
|---|---|---|
| [Grafana](https://github.com/grafana/grafana) 11 | **AGPL-3.0** | Obligation applies only if you **modify** Grafana's source and offer it as a network service. The stock image imposes nothing on you. |
| [Eclipse Mosquitto](https://github.com/eclipse/mosquitto) | EPL-2.0 / EDL-1.0 (dual) | |
| [InfluxDB](https://github.com/influxdata/influxdb) 2.x | MIT | |
| [Telegraf](https://github.com/influxdata/telegraf) | MIT | |
| [Traefik](https://github.com/traefik/traefik) | MIT | |
| [nginx](https://nginx.org/) | BSD-2-Clause | |

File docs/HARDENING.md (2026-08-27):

# freezerMon — Security Hardening

Started 2026-07-14, after cellular OTA was proven working. Threat model and
prioritized plan. The OTA path is the highest-value surface: a compromise there
means arbitrary code execution on the device.

## Threat model — findings, prioritized

| P | Finding | Status |
|---|---|---|
| **P0** | **OTA command channel is unauthenticated** (`authmode=0`). A MITM can push a malicious OTA cmd; MD5 gives no protection. | **✅ DONE — signed OTA (2.49)** |
| **P1** | **`/update` local flash accepts any image** (behind the shared WPA2 AP password). | **✅ DONE — signed `/update` (2.49)** |
| **P2** | **Downgrade allowed** (`ota_ver != FW_VERSION`) → old signed-but-vulnerable version can be pushed. | **✅ DONE — `verNewer()` + version bound into the signature (2.50)** |
| **P3** | **Secrets compiled into the binary** (MQTT + AP passwords). **Re-rated 2026-08-26: remotely extractable, not just via flash dump** — the OTA pieces are served over plain HTTP behind `OTA_PATH_TOKEN`, which travels in the clear on every fetch and inside the unauthenticated MQTT session. Note: the committed *example* `DEBUG_AP_PASSWORD` is weak — must be unique + high-entropy per unit. | **Open — per-device NVS-provisioned creds is the real fix.** Mitigated: unsplit `firmware.bin` no longer published; broker ACLs (P6) confine a leaked credential to telemetry/alert of the shared identity. |
| P4 | Info disclosure on the debug console (`/lte`, `/gps`, `/sms`, `/log`) — behind WPA2. **Re-rated 2026-08-26:** on externally-powered units the AP and every endpoint are up 24/7 (`main.cpp` "console always on while powered"), not for a 120 s window, behind one fleet-wide PSK. | Medium on powered units — on-demand AP + per-unit PSK pending |
| **P5** | **Availability: OTA pull was unbounded.** `performOta` fed the watchdog on every retry and never checked the awake budget; the retained `cmd` re-arms on every subscribe. A `cmd` pointing at a stalling server = hours awake per wake, forever, remotely (anyone who can write `cmd`, or the P0 MITM). | **✅ DONE (2.69)** — `MAX_OTA_MS` cap + NVS failure memory (`OTA_MAX_FAILS`) |
| **P6** | **No broker authorization.** One shared credential (devices + Telegraf) with no `acl_file` could write any `freezer/*/cmd` (fleet-wide P5) and forge any unit's telemetry (the Grafana breach rule reduces `last()`, so a forged low reading clears a real alert). | **✅ DONE for `cmd`** — `mosquitto/config/acl`: per-device `pattern %u` rules, shared device user cannot write `cmd`, read-only `telegraf`, `cmd`-only `publisher`. **Residual until P3:** the shared `freezer` credential can still publish to any `freezer/+/telemetry` / `/alert`, so a holder can forge another unit's readings (and clear its breach alert). Remove the `user freezer` block once every unit has its own credential. |
| **P7** | **Debug-console concurrency.** dbgweb task and main thread shared the modem UART, the flash writer and the log ring behind an advisory `modemBusy` bool that `/lte` cleared unconditionally and `/sms` ignored; `String logRing[]` was a use-after-free between `logLine` and `/log`. Reachable by anyone with the AP PSK. | **✅ DONE (2.69)** — recursive FreeRTOS mutex owns the UART (console try-takes, answers busy; `/sms` guarded), fixed `char` ring under a spinlock, `modemBusy` written by the main thread only and restored (not cleared) by nested OTA paths |
| P8 | CSRF on the console: `/setname` Origin check failed open on a missing header; `/update` and `/update/check` had no check — a drive-by page on the AP could erase the inactive OTA slot and block cellular OTA for 3 min. | **✅ DONE (2.69)** — `sameOriginRequest()` fail-closed on all three, enforced in the upload callback before `Update.begin` |
| P9 | `PublishFirmware.ts` built a remote root shell command by string concatenation from unvalidated argv (`JSON.stringify` is not shell quoting). | **✅ DONE** — argv validated against the firmware's own contracts, payload on stdin, `publisher` identity |

## Round 5 — gate on the 2.87→2.96 train + Signal alerting (2026-08-27, opencode Kimi K3 ×2; GPT-5.5/5.3 runs hung)

Security: **CHANGES REQUESTED** — 1 HIGH: the `signal-cli-rest-api` port (no auth, full control of the owner's
Signal account) stayed published on the host loopback after device linking → unpublished, documented as
link-time-only; relay had no input limits → 64 KB body cap, printable-text sanitizer, 1500-char messages,
honest 502; the echo delivery-proof accepted any frame on the topic → matched on this frame's own `seq`
(first key, offset 0); `/status` torn read → spinlock; images pinned; README now states that the shared
device credential can read every unit's telemetry (coordinates) until per-device credentials (P3).
Correctness: the reviewer's BLOCKER (liveness guard "dead code") was overstated — the guard is live for the
early-return paths it was written for — but its `lastReportMs` now means *last successful report*; the
same-ts follow-up / stale-`crash_log`-quote echo ambiguity and the unsynced-clock (`ts == 0`) never-clears
case are both closed by the `seq` match; `crash_log` is budgeted against the complete frame. **Deferred:**
a Grafana Editor could push text to the owner's phone via the contact-point test (no Editors exist; the
operator is a Viewer); the global OTA failure counter can lock an operator out after 6 bad pulls until a
real install (intended); `otaUrlSafe` pins host but not port/scheme (OTA is plain HTTP by design, signed).

## Round 4 — gate on the 2.69→2.86 train (2026-08-27, opencode GPT-5.5 + Kimi K3, plus a Claude-family auditor)

Three reviewers that did not author the train (`cdb379f..14e528a`) confirmed all six round-3 HIGH fixes as real
(mutex-owned UART, char log ring, fail-closed CSRF hoisted before `Update.begin`, OTA cap + failure memory, ACL
`cmd`-write ban, hardened publish script). They found the train's own new surface wanting — all fixed in 2.87:
the pending-fix clear depended on an optional cmd downlink (a fleet with no retained OTA republished a fix forever)
→ now verified by the broker echoing the device's own retained frame; per-version OTA failure memory was evadable by
cycling `ota_ver` → global consecutive counter, reset only by a real install; `crash_log` shipped raw device/cmd
strings and could push a frame over the buffer and suppress a whole boot's telemetry → sanitized, budgeted, capped
at the log sites; `${device}` was raw-interpolated into 19 Flux queries (a Viewer could inject Flux via the URL) →
`${device:regex}`; `PublishFirmware.ts` sourced the server `.env` as root shell → read with `sed`; scoped InfluxDB
tokens replaced the shared admin token. **Recorded residuals:** the shared `freezer` credential can still forge any
unit's telemetry/alert until per-device credentials (P3); Mosquitto `pattern` rules also grant service identities
write on `freezer/<their-username>/*`; `/gps` and `/lte` are GET endpoints with modem side effects behind the AP PSK.

## Round 3 — full-codebase `/independent-review` gate (2026-08-26)

Two reviewers that did not author the code (`Cato` correctness/design, `Silas` security) audited the
entire tree at `cdb379f`. Both independently confirmed the signed-OTA core: exactly two `Update.end(true)`
sites, both behind `otaCheckSig` over `version‖0x00‖image`; anti-rollback correct; piece reassembly bounded;
`deviceNameValid` blocks topic/SSID injection; no secrets in tracked files. Verdict was **CHANGES REQUESTED**
on 6 HIGHs, none in the crypto — P5–P9 above are those findings, fixed in fw 2.69 + this infra revision.
Still open from that gate: P3 (per-device NVS credentials — the only real fix for secrets-in-image), P4
(on-demand AP / per-unit PSK on powered units), TLS-by-default for the broker, scoped InfluxDB tokens,
Telegraf-side `device` tag validation, and a handful of MEDIUM correctness items in the firmware
(`/status` re-reading OneWire from the console task, door-wake buffer timestamp drift, ddmm parse heuristic,
`reportsSinceGps` not NVS-mirrored, Grafana offline-rule lookback). Full table in the session log.

## Independent review (2026-07-14) — outcomes

Two reviewers who did not write the code audited the signed-OTA diff (SSDLC gate).

- **Security review:** the signature gate **holds** — no path installs firmware without a valid signature for the MITM adversary. Verified gate order, hash-covers-flashed-bytes, correct mbedTLS usage, fail-closed `.sig` handling, clean key management.
- **Correctness review — found a CRITICAL bug (now fixed):** the 256-byte `.sig` was fetched over the same HTTP path that has the **3072-byte tail-drop**; since 256 < 3072 the modem may return **nothing**, so **every signed OTA would fail to install**. Fix: the server pads `firmware.bin.sig` to `256 + 4096` and the device reads only the first 256 bytes (same tail-skip trick as the image pieces). Verified: the padded file's first 256 bytes verify OK.
- Also fixed: the manifest "check online" path now sets `ota_size`/`ota_skip`/`ota_md5` (was stale).

### Round 2 — formal `/independent-review` gate (2.50)

A second independent gate (`general-purpose` + `Silas`) **both independently** found a HIGH the
first pass missed: **anti-rollback was cryptographically unenforced** — the signature covered the
image bytes only, so a MITM could relabel any previously-signed image with a higher `ota_ver` and
force a **downgrade**. Fixed in 2.50:

- **HIGH — version binding:** the signature is now over **`version ‖ 0x00 ‖ image`** (server +
  device + `/update`), so a mismatched `ota_ver` fails verification. `verNewer()` + this binding
  together enforce anti-rollback cryptographically.
- **MED — AT-command injection:** `otaUrlSafe()` rejects OTA URLs with CR/LF/quote/control chars
  or bad length before they reach `AT+HTTPPARA`.
- **LOW:** `/update`↔cellular-OTA mutex (`otaUploadActive`); `mbedtls_md_setup/starts` returns now
  checked; `.sig`/hash init failures abort cleanly.
- **Tests:** `infra/scripts/ota.test.ts` pins the tiling invariant, the version-bound sign/verify,
  the downgrade-rejection, and the `verNewer` truth table.

### Round 2 verdict + round 3 (focused re-review) — 2.51, gate PASS

Round 2 confirmed cellular anti-rollback + AT-injection CLOSED but caught a HIGH: the `/update`
version-binding was a **no-op** (`arg("ver")` is empty during the multipart upload callback — the
ESP32 WebServer merges form fields into `_currentArgs` only *after* the callbacks). Fixed in 2.51 by
passing `ver` in the **URL query string** (`/update?ver=…` via the form's `onsubmit`), which a
focused independent re-review **verified against the vendored WebServer parser** is available during
the callback — the `/update` fix is now **CORRECT and FAIL-CLOSED**. Also added: empty-`ver` guard,
`md_setup/starts` return checks on `/update`, a 3-min staleness backstop for `otaUploadActive`, and
an ephemeral-keypair fallback so the signature tests never silently skip.

**Gate PASS (2.51):** no BLOCKER/HIGH. Deployed to the device via WiFi `/update` (a trusted local
channel) as the signing trust anchor.

**MEDIUM + LOWs — FIXED (2.52):** the TOCTOU race is closed with a `portMUX` critical section
(`flashMux`) making each path's claim (check the other's flag + set mine) atomic — the transfer
itself is not held under the lock. `/update` now checks `Update.begin/write` returns (abort + reject
on failure, free the hash ctx), and the version input uses an `id` (no multipart field) so the
`?ver=` query arg can't be shadowed. All addressed as targeted responses to the focused-review
findings; 22/22 tests green.

## Deployment — the trust anchor MUST be UART-flashed

Signed OTA only protects devices *already running* signature-verifying firmware. The
one-time transition from pre-signing firmware (≤2.48) is itself unauthenticated, and
2.48's `.sig` fetch is broken (pre-fix). **Flash 2.49 over UART** to establish the
anchor over a trusted channel. From 2.49 onward, LTE OTA is signed + enforced +
anti-rollback, and 2.49→2.50 is the first real over-the-air signed-update test.

Not in scope without explicit approval: **ESP32 Secure Boot** (eFuse-based,
irreversible, bricking risk). App-level signing below gives most of the benefit
with none of that risk.

## P0 — Signed OTA (image authenticity)

**Design:** RSA-2048 + SHA-256, verified on-device with mbedTLS (already present via
the TLS stack — no new dependency). The signature is transport-independent, so it
holds even though the command channel and the HTTP download are not authenticated.

- **Keys:** `infra/keys/ota_sign_priv.pem` (gitignored, build-host only) +
  `ota_sign_pub.pem`. Public key embedded in `firmware/include/ota_pubkey.h`
  (committed — public half only).
- **Server (`PublishFirmware.ts`):** signs `firmware.bin` →
  `firmware.bin.sig` (`openssl dgst -sha256 -sign`), uploaded alongside the pieces.
- **Device (`performOta`):** streams SHA-256 over the bytes written to flash, fetches
  `<url>.sig`, and verifies the RSA signature against `OTA_PUBKEY_PEM` **before**
  `Update.end`. A bad/absent signature aborts the install. (MD5 is kept as a cheap
  pre-check for accidental corruption.)

Why the sig can ride over plain HTTP: it is unforgeable without the private key, and
the public key is baked into the firmware — a MITM can swap the sig, but can't make
one that verifies. This defeats both the MITM'd-command attack (P0) and, once
`/update` checks it too, the local-flash attack (P1).

## P1 — Gate `/update` on the signature (done, 2.49)

Route the browser/WiFi flash through the same signature check so only signed images
install by any path.

## P2 — Anti-rollback (done, 2.50)

Reject `ota_ver` numerically older than the running `FW_VERSION` unless an explicit
override is set.

## Key management

- **Initial setup (every deployment):** run `bun infra/scripts/GenSigningKey.ts` once,
  from the repo root, before building firmware. It generates the RSA-2048 keypair,
  writes the private key to `infra/keys/ota_sign_priv.pem` (gitignored, build-host
  only), and (re)writes `firmware/include/ota_pubkey.h` (committed). The repo ships a
  **placeholder** `ota_pubkey.h` (the original author's public key) that you MUST
  replace with your own — otherwise you can't sign updates (you don't hold the private
  key) and your fleet would trust someone else's key.
- **Rotation (if the private key is exposed):** delete `infra/keys/ota_sign_priv.pem`,
  re-run `GenSigningKey.ts`, and ship the new `ota_pubkey.h` via a **UART flash** — a
  compromised key can't sign the transition, so OTA can't be trusted for it.

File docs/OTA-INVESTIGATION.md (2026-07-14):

# Cellular OTA Investigation — LilyGO T-A7608E-H

**Status: ✅ WORKING (2026-07-14).** Cellular OTA self-update proven end-to-end —
the device pulled a full ~900 KB image over LTE, MD5-verified it, installed, and
rebooted into the new version (2.44 → 2.45, all 32 pieces, retries absorbed).

## The working recipe (TL;DR)

1. **Split the image into overlapping pieces** (`PIECE = 32768`, `OVERLAP = 4096`,
   `STEP = PIECE − OVERLAP = 28672`). Piece *i* = `image[i*STEP : i*STEP + PIECE]`;
   the short final piece is zero-padded by `OVERLAP`. Ship `ota_skip = OVERLAP`,
   `ota_size`, and `ota_md5` in the retained cmd.
2. **Device reads only the deliverable prefix** `min(plen − ota_skip, remaining)`
   of each piece — this dodges the modem's **3072-byte tail-drop** (see below), and
   the overlapping prefixes tile the image with no gap.
3. **Stage each piece fully in RAM, always reading from offset 0**, and commit to
   flash only after a clean read. On any read failure, **re-fetch and re-read the
   whole piece from 0** (up to `MAX_TRIES`=10). Never resume at a non-zero offset — the modem's
   offset-read after a re-fetch returns wrong bytes and corrupts the image.
4. **MD5-verify the whole image** (`Update.setMD5`) so a corrupt assembly is
   rejected, never installed.

Implementation: `firmware/src/main.cpp` → `performOta()`; `infra/scripts/PublishFirmware.ts`.

## ⚠️ Debugging gotcha that cost hours

The public proxy container is named **`traefik`** and the OTA backend is
**`freezermon-ota-1`** (nginx). Tailing a *non-existent* `freezermon-traefik-1`
returned empty and looked exactly like "the device isn't fetching" — when it was.
**Watch `docker logs freezermon-ota-1`** for real OTA fetch activity. Also: the
server's own shell resolves `freezer.example.com` via a hairpin that 404s; test the
public URL from an external host (or the device) instead.

---

## Goal

Let `cooler-01` self-update its ~900 KB firmware image over the cellular link,
so we never have to physically UART-flash a deployed unit again. The device pulls
a new image when the retained MQTT command on `freezer/cooler-01/cmd`
(`{ota_url, ota_ver, ota_size}`) names a version different from its own
`FW_VERSION`, provided battery ≥ `OTA_MIN_VBAT_MV` (3700 mV).

Everything **except** the over-the-air image transfer works: telemetry, MQTT over
TLS, GNSS, the retained-command trigger, the split-image server pipeline, and
browser/WiFi flashing of the same image.

## The root constraint

The firmware is compiled with **`TINY_GSM_MODEM_A76XXSSL`** because MQTT-over-TLS
needs the modem's **CCH/SSL** application stack. That locks us out of the plain
**CIP TCP/IP** stack (`AT+NETOPEN`/`CIPOPEN`/`CIPRXGET`) that virtually every
working TinyGSM OTA example — including the reference sketch we were sent — relies
on. The entire investigation has been an effort to move ~900 KB through the modem
using only the services available alongside CCH: the modem's **HTTP** application
(`AT+HTTPINIT`/`HTTPACTION`/`HTTPREAD`) and the CCH channel itself.

## What the A7608 modem actually does (hard-won facts)

- **No `HTTPREADFILE` / `FSATTRI` / `CFTRANTX`.** Those file-system HTTP commands
  are A7670E-only; on the A7608 they return `ERROR`.
- **HTTP response cache ≈ 57 KB.** A single `HTTPACTION` GET larger than this
  can't be fully read back with `HTTPREAD`.
- **Won't cache `206 Partial Content`.** Ranged GETs (Range header via
  `HTTPPARA "USERDATA"`) return `206` with `content-length 0` to `HTTPREAD`.
- **`HTTPREAD` streams in ~4 KB chunks.** One `AT+HTTPREAD=<off>,<size>` call
  emits one *or more* `+HTTPREAD: <n>` data blocks (≈4 KB each) terminated by
  `+HTTPREAD: 0`. Non-zero offsets do work.
- **CCH plain-TCP reads stall ≈ 344 KB.** The CCH RX path wedges partway through a
  large streamed download; keep-alive second requests and CCHSTART-after-CCHSTOP
  reconnects fail; sharing the CCH channel with the live MQTT session corrupts reads.

## Approaches tried, in order

| # | Approach | Firmware | Result |
|---|---|---|---|
| 1 | Stream image over the **CCH** TCP channel (mux 1) | early | Stalls ≈344 KB; no keep-alive; reconnect fails; MQTT/OTA channel-sharing corrupts reads. **Dead end.** |
| 2 | Pull to **modem filesystem** (`HTTPREADFILE`/`FSATTRI`) | 2.24–2.27 | A7608 lacks these commands (`rf:ERROR`, `fs:ERROR`). **Dead end.** |
| 3 | Single GET, read back from **HTTP cache** with `HTTPREAD` | 2.28–2.29 | Reads to ≈58 KB then `ERROR` — 57 KB cache ceiling. **Dead end for a full image.** |
| 4 | **Ranged GETs** (Range header) to page the image | 2.30–2.31 | `206`, `content-length 0` — modem won't cache partials. **Dead end.** |
| 5 | **Split image into 48 KB pieces** server-side; each piece a plain `200` GET that fits the cache; `HTTPREAD` each piece out and concatenate into the OTA slot | 2.32 → 2.38 | Piece *download* works reliably (Traefik confirms `200`/49152 B). The read-out is where the remaining bugs lived — see below. |

### The piece-split read-out saga (approach 5)

The server pipeline (`infra/scripts/PublishFirmware.ts`) splits `firmware.bin`
into `firmware.bin.000`, `.001`, … (48 KB each, under the 57 KB cache) and the
device fetches them sequentially, `HTTPREAD`-ing each into `Update.write()`.
Downloads always worked; every failure was in reading bytes out of the modem into
flash:

| Firmware | Failed at | Cause | Fix applied |
|---|---|---|---|
| 2.32 | byte **4096** | Read only the *first* `+HTTPREAD` chunk per call, then skipped the rest → stream desync, next read errored | Read **all** `+HTTPREAD:` chunks per call until `+HTTPREAD: 0` → 2.34 |
| 2.34 | byte **46080** | `RD=16384` makes the modem burst four 4 KB chunks back-to-back; while `Update.write()` stalled on a flash-sector erase, the burst overran the **256-byte default UART RX buffer**, dropping bytes | Enlarge `SerialAT` RX buffer to 32 KB → 2.36 |
| 2.36 | **byte 0** (no GET at all) | The 32 KB RX buffer starved the heap; `performOta`'s `malloc(16384)` failed under the live WiFi AP + MQTT TLS, so OTA aborted (`[ota] no buf`) **before its first request** — server saw zero fetches on every wake | `RD=4096` (modem sends one chunk then waits — no burst possible), 8 KB RX buffer, **static** OTA buffer (no `malloc` to fail); log free heap → 2.38 |
| 2.38 (48 KB pieces) | byte **46080** | Modem drops the tail of the cached response (see below) | Thought to be a ~46 KB cache wall → shrink pieces to 16 KB |
| 2.38 (16 KB pieces) | byte **13312** | **Same bug, smaller piece** — `16384 − 3072`, exactly as `49152 − 3072 = 46080` | Refined diagnosis: fixed **3072-byte tail-drop**; needs a firmware fix, not a piece-size change |

### The 3072-byte tail-drop (the actual root cause)

Two `/log` captures with different piece sizes were decisive:

```
# 48 KB pieces:              # 16 KB pieces:
[ota] 2.39 ... heap 219872   [ota] 2.39 ... heap 220564
[ota] read err p0 @46080     [ota] read err p0 @13312
[ota] failed at 46080/…      [ota] failed at 13312/…
```

Line them up: `49152 − 46080 = 3072` and `16384 − 13312 = 3072`. **The failure is a
fixed 3072-byte deficit from the end of the piece, independent of piece size.** The
modem reports the full `Content-Length` in `+HTTPACTION` but only ever caches
`length − 3072`, then `ERROR`s (it hands back a final partial ~1 KB chunk and quits).

This kills the "shrink the pieces" idea: **every piece loses its last 3072 bytes**,
so no split size helps — 16 KB failed *sooner* (13312), not later. It also corrects
the earlier "~46 KB wall" reading (46080 was just `48 KB − 3072`) and the "58368"
mark from 2.28.

Also ruled out along the way: `heap 219872/220564` → **220 KB free** (not heap);
identical deficit across two different images/code (not overflow or data-dependent);
`reset=poweron` and the unit on **USB + 18650** (not brownout — the "reboot loop" was
a misread of the telemetry `boot` field, which counts *packages since boot*, not
reboots; the device was stable throughout).

**Fix requires a firmware change** (no longer server-side-only):

- **Overlap + tail-skip.** Server overlaps pieces by ≥4 KB and pads the final piece;
  firmware reads only `plen − 4096` per piece (skipping the undeliverable tail) and
  writes exactly `ota_size` bytes total. Bounded change, directly defeats the drop.
- **CIP-stack rework.** Bypass the modem's HTTP app entirely (raw
  `NETOPEN`/`CIPOPEN`/`CIPRXGET`); avoids the tail-drop *and* the four earlier HTTP-app
  bugs. More work, most robust.

**Secondary open question:** the device attempts OTA reliably on a **power-on boot**
but was not observed attempting on **timer wakes** — no gate for that is visible in
the wake handler.

## Corroboration from the field

This is a well-known SIMCom limitation, not something peculiar to our setup — and
independent reporters landed on the same workaround we built.

- **SIMCom's own AT manual** documents the mechanism: *"The maximum size of protocol
  stack is 64K bytes for most modules (the CAT4 module is 10K bytes), and when the
  total size of the data from server is bigger than that and 'READMODE' is 0, you
  should read the data quickly or you will fail to read it,"* and *"the size of HTTP
  server response content should be shorter than 1M."* The A7608 is a Cat-4 module —
  the family called out as having the *smaller* buffer. The exact figure is
  firmware/SKU-dependent (nominal 64K, "Cat-4" 10K, ours ~46K). `READMODE`/"read
  quickly or lose it" also explains our 344 KB CCH streaming stall.
- **[LilyGO Modem-Series #352](https://github.com/Xinyuan-LilyGO/LilyGo-Modem-Series/issues/352)**
  (SIM7670G OTA) reproduces all three of our symptoms: full-image GET fails with
  `+HTTPACTION: 0,706,0` (insufficient storage); *"after ~10 KB, attempting to set a
  new range always results in an error"* → *"the only way to continue is to restart
  the HTTP session"*; past ~100 KB, responses report the right length but return no
  payload — *"even with the official example code."*
- **[Arduino Forum — HTTPREAD buffer size](https://forum.arduino.cc/t/how-can-we-change-simcom-at-command-httpread-response-buffer-size/1122235)**
  confirms HTTPREAD fragments its output into fixed chunks (1024 B there, ~4 KB here)
  with repeated `+HTTPREAD:` headers and **no AT command to change it** — the exact
  behaviour that broke our fw 2.32.

The community consensus fix — split into sub-buffer chunks and **restart the HTTP
session per chunk** (`HTTPTERM`/`HTTPINIT`) — is precisely our `firmware.bin.NNN`
approach with a fresh session per piece. Range-header paging is widely reported as
unreliable (the `206` / "new range errors" problem — matches our `206, len 0`), so
separate small `200` GETs are the robust path. Sibling chips wall as low as 10 KB,
which is why we chose 16 KB pieces rather than staying near our measured ~46 KB.

## The flash-then-publish testing dance

Because the OTA read logic runs *on the device*, any fix to it must be UART-flashed
before it can be exercised — the running (buggy) firmware can't self-update using a
fix that only exists in the new image. So each round is: flash version *X* over
UART (which contains the fix), publish a cmd for *X* (so the freshly-flashed unit
doesn't see a stale older cmd and try to **downgrade**), then publish *X+1* to test
whether *X*'s OTA path pulls it. That's why the version numbers climb two at a time.

## Current device state

- Running **fw 2.38**, healthy and **stable**: MQTT/TLS up, telemetry flowing,
  `vbat ≈ 4290 mV` and rising (charging on USB + 18650), GNSS fix present. There
  was **no reboot loop** — that was a misread of the telemetry `boot` field (packages
  since boot, not reboots). It attempts OTA only on power-on boots, and each attempt
  fails cleanly at the tail-drop then continues; the unit is doing its job.
- Retained cmd **neutralised to 2.38** (matches current fw → no OTA attempts) since
  16 KB pieces don't fix the tail-drop. Re-arm 2.39 only alongside a real fix.
- All non-OTA functionality is production-ready.

## Options for when this is unparked

1. **Overlap + tail-skip firmware fix (one flash).** Server overlaps pieces by ≥4 KB
   and pads the last piece; firmware reads `plen − 4096` per piece and writes exactly
   `ota_size` bytes. Bounded change that directly defeats the 3072-byte tail-drop.
2. **CIP-stack OTA path (bigger flash).** Raw `AT+NETOPEN`/`CIPOPEN`/`CIPRXGET`,
   bypassing the modem's HTTP app (and all five of its bugs) for the download while
   MQTT keeps CCH. The stack the working reference sketch (`TINY_GSM_MODEM_A7608`)
   uses; most work, most robust.
3. **Accept UART/WiFi-only updates.** The unit is deployed and working; OTA is a
   convenience, not a functional requirement. Current resting state.

Secondary: **why timer wakes skip the OTA attempt** (only power-on boots attempt) —
no gate is visible in the wake handler; needs a fresh timer-wake `/log`.

## References

External (the tail-drop and its workaround):

- [SIMCom SIM7X00 HTTP AT Command Manual (PDF)](https://simcom.ee/documents/SIM7X00/SIM7500_SIM7600_SIM7800%20Series_HTTP_AT%20Command%20Manual_V1.00.pdf)
  and [A7600 Series AT Command Manual (PDF)](https://www.elecrow.com/wiki/image/d/dd/A7600_Series_AT_Command_Manual_V1.01.pdf)
  — the 64K/10K protocol-stack buffer + READMODE + 1M response-size spec.
- [LilyGO Modem-Series #352](https://github.com/Xinyuan-LilyGO/LilyGo-Modem-Series/issues/352)
  — SIM7670G OTA: the 10 KB range-error / restart-session / >100 KB empty-read pattern.
- [LilyGO Modem-Series #443](https://github.com/Xinyuan-LilyGO/LilyGo-Modem-Series/issues/443)
  — OTA over LTE (modem-FS and split approaches).
- [LilyGO Modem-Series #416](https://github.com/Xinyuan-LilyGO/LilyGo-Modem-Series/issues/416)
  — GitHub-based OTA with SIM7670G.
- [Arduino Forum — changing SIMCom HTTPREAD buffer size](https://forum.arduino.cc/t/how-can-we-change-simcom-at-command-httpread-response-buffer-size/1122235)
  — HTTPREAD fixed-chunk fragmentation, not configurable.

Internal:

- Firmware OTA implementation: `firmware/src/main.cpp` → `performOta()`.
- Server publish pipeline: `infra/scripts/PublishFirmware.ts`.
- Plain-HTTP `/fw/` routing: `infra/docker-compose.traefik.yml`.

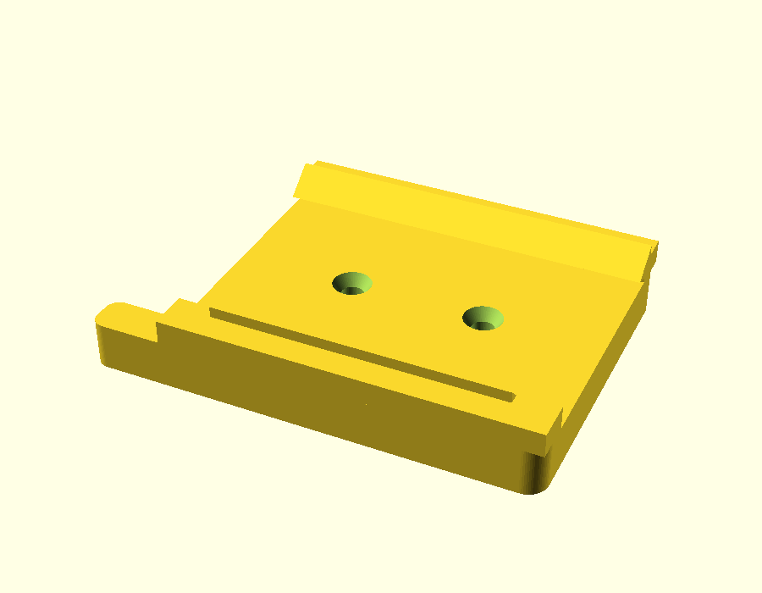
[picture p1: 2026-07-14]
hardware/preview-clip.png

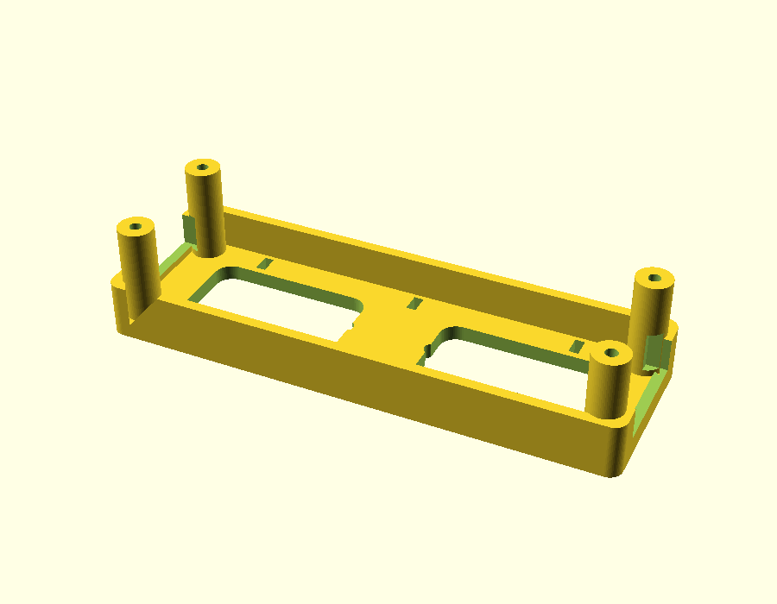
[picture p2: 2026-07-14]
hardware/preview-tray.png

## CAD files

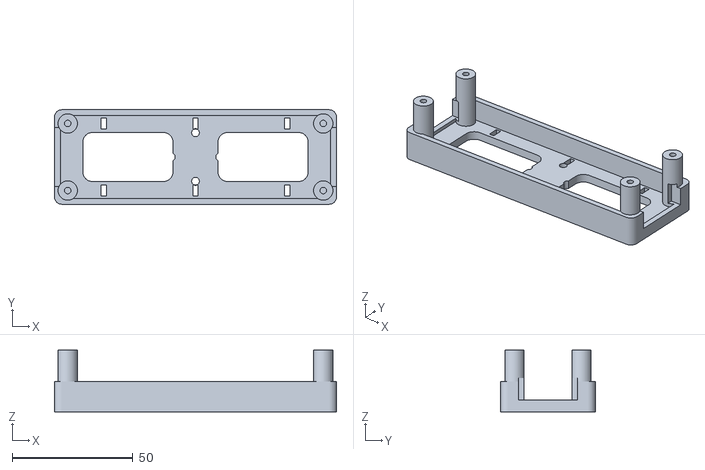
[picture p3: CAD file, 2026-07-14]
hardware/TrayT-A7608.stl
116.5 x 39.1 x 25.5

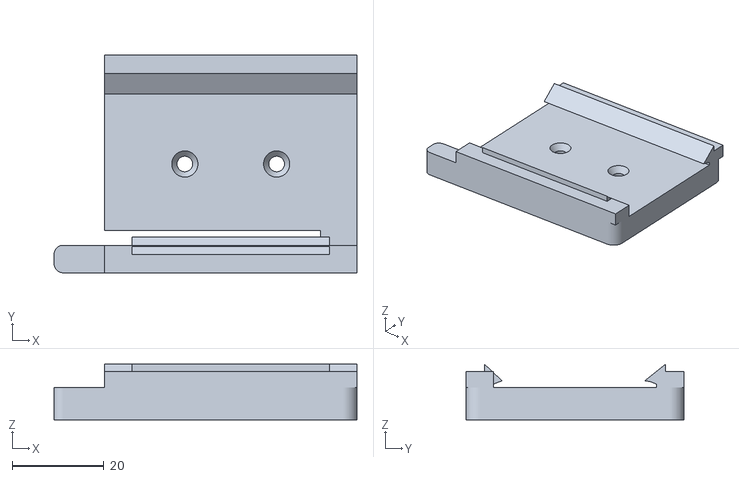
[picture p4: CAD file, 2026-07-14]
hardware/DinClipTS35.stl
66.0 x 47.4 x 12.1

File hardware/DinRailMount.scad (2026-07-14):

// freezerMon — DIN-rail mount for LilyGO T-A7608E-H (ESP32 version, with GPS)
// ---------------------------------------------------------------------------
// Two-piece, support-free print for Bambu Lab (or any FDM) printers:
//   part = "tray"  — board cradle: 4× M3 standoffs on the official hole grid,
//                    22 mm tall so the 18650 holder on the PCB back hangs free,
//                    stiffening skirt, zip-tie slots for antenna/sensor cables
//   part = "clip"  — TS35 (top-hat 35 mm) DIN clip, fixed top hook + printed
//                    spring latch with screwdriver release tab
//   part = "both"  — assembly preview (do not print this)
//
// Rail orientation: the tray floor carries a 4-boss cross, so the SAME tray and
// clip mount the unit either way — set `mount` for the preview, and at assembly
// bolt the clip straight (horizontal) or turned 90° (vertical). No reprint needed.
//
// Board dimensions from LilyGO's official drawing (T-A7608X-ESP32.dxf):
//   PCB 33.07 × 110.54 mm, M3 holes (R1.73) on a 27.72 × 105.59 mm grid.
//
// Print: PETG recommended (freezer room / cabinet duty), 0.2 mm layers,
// 4 walls, 40 % infill on the clip. Tray prints cavity-up, clip channel-up —
// no supports. Hardware: 4× M3×6 (board→standoffs, self-tap into 2.7 mm
// holes) + 2× M3×10 countersunk (clip→tray bosses).
// ---------------------------------------------------------------------------

part  = "both";           // "tray" | "clip" | "both"
mount = "horizontal";     // preview/assembly only: how the unit hangs on the rail.
                          //   "horizontal" — board landscape, long axis ALONG the rail
                          //   "vertical"   — board portrait, long axis ACROSS the rail
                          // The same tray + clip serve both; for vertical you simply
                          // bolt the clip on rotated 90° (it picks up the other boss pair).

/* ---------- board (measured: LilyGO official DXF) ---------- */
board_l   = 110.54;       // PCB length
board_w   = 33.07;        // PCB width
hole_dx   = 105.59;       // mounting-hole grid, long axis
hole_dy   = 27.72;        // mounting-hole grid, short axis
screw_d   = 2.7;          // M3 self-tap pilot in standoffs

/* ---------- tray ---------- */
clearance   = 0.6;        // PCB outline to skirt, per side
floor_t     = 3.5;
skirt_h     = 9;          // stiffening skirt above floor
skirt_t     = 2.4;
standoff_h  = 22;         // 18650 holder on PCB back needs ~20.5 mm
standoff_d  = 8;
ziptie_w    = 4.5;        // fits 3.6 mm ties
ziptie_t    = 2.2;

/* ---------- DIN clip (TS35×7.5 top-hat rail) ---------- */
rail_w        = 35.0;     // rail outer height (across)
rail_fit      = 0.4;      // pocket clearance
lip_t         = 1.3;      // rail lip metal thickness + margin
clip_t        = 7;        // clip plate thickness
clip_len      = 55;       // along the rail
clip_screw_dx = 20;       // clip↔tray screw spacing (M3, countersunk)

/* ---------- derived ---------- */
inner_l = board_l + 2*clearance;
inner_w = board_w + 2*clearance;
outer_l = inner_l + 2*skirt_t;
outer_w = inner_w + 2*skirt_t;
clip_w  = rail_w + rail_fit + 2*6;   // plate width across rail incl. hook stock

// clip-screw cross pattern: X pair = landscape mount, Y pair = vertical (90°) mount
clip_screw_pts = [ [ clip_screw_dx/2, 0], [-clip_screw_dx/2, 0],
                   [0,  clip_screw_dx/2], [0, -clip_screw_dx/2] ];

$fn = 64;

/* =========================== TRAY =========================== */
module tray() {
  difference() {
    union() {
      // floor
      linear_extrude(floor_t) rrect(outer_l, outer_w, 3);
      // skirt
      linear_extrude(floor_t + skirt_h)
        difference() {
          rrect(outer_l, outer_w, 3);
          rrect(inner_l, inner_w, 2);
        }
      // standoffs on the official hole grid
      for (sx = [-1, 1], sy = [-1, 1])
        translate([sx*hole_dx/2, sy*hole_dy/2, 0])
          cylinder(h = floor_t + standoff_h, d = standoff_d);
      // clip screw bosses — cross pattern so ONE tray serves both rail orientations:
      // the X pair carries the clip landscape, the Y pair carries it rotated 90° (vertical).
      for (p = clip_screw_pts)
        translate([p[0], p[1], 0])
          cylinder(h = floor_t, d = 9);
    }
    // standoff pilot holes (M3 self-tap)
    for (sx = [-1, 1], sy = [-1, 1])
      translate([sx*hole_dx/2, sy*hole_dy/2, floor_t + standoff_h - 8])
        cylinder(h = 9, d = screw_d);
    // clip screws: M3 clearance through the floor (both boss pairs)
    for (p = clip_screw_pts)
      translate([p[0], p[1], -1])
        cylinder(h = floor_t + 2, d = 3.2);
    // zip-tie slots through the floor, along both long edges
    for (sx = [-1, 0, 1], sy = [-1, 1])
      translate([sx*(inner_l/2 - 18), sy*(inner_w/2 - ziptie_w/2 - 1), -1])
        linear_extrude(floor_t + 2)
          square([ziptie_t, ziptie_w], center = true);
    // lightening / airflow windows under the modem & battery zone
    for (sx = [-1, 1])
      translate([sx*inner_l/4, 0, -1])
        linear_extrude(floor_t + 2) rrect(inner_l/3, inner_w - 14, 4);
    // skirt cable openings, both short ends (USB-C, JST, antenna pigtails)
    for (sx = [-1, 1])
      translate([sx*outer_l/2, 0, floor_t + skirt_h/2 + 1.5])
        cube([skirt_t*4, inner_w - 10, skirt_h], center = true);
  }
}

/* =========================== DIN CLIP =========================== */
// Printed channel-up. Hook the fixed (+Y) side over the rail's top lip, press
// down: the spring arm (-Y) cams open and snaps over the lower lip. Pull the
// tab (or lever a screwdriver under it) to release.
//
// Built as ONE extruded footprint — slab + spring arm + release tab — with a
// single slot freeing the arm, so the solid is manifold by construction.
module clip() {
  inner  = (rail_w + rail_fit) / 2;    // pocket half-width (17.7)
  bar_w  = 6;                          // hook stock width
  slot_w = 3.2;                        // gap that frees the spring arm
  bridge = 8;                          // arm anchor at the +X end
  hook_h = lip_t + 2.2;                // hook stock height above the plate
  half_w = inner + bar_w;              // plate half-width across the rail
  tab_l  = 11;

  difference() {
    union() {
      // one footprint: plate + arm + tab, minus the arm-freeing slot
      linear_extrude(clip_t)
        difference() {
          union() {
            rrect(clip_len, 2*half_w, 3);
            // release tab, overlapping the arm's free end by 3 mm
            translate([-clip_len/2 - tab_l/2 + 3, -(inner + bar_w/2)])
              rrect(tab_l + 6, bar_w, 2);
          }
          // slot between slab and arm; the last `bridge` mm stay attached
          translate([-clip_len/2 - tab_l - 1, -inner])
            square([clip_len + tab_l + 1 - bridge, slot_w]);
        }
      // hook stock bars
      for (sy = [-1, 1])
        translate([-clip_len/2, sy > 0 ? inner : -inner - bar_w, clip_t])
          cube([clip_len, bar_w, hook_h]);
      // fixed hook nose (+Y, deep engagement) — 45° underside chamfer
      translate([0, inner, clip_t]) nose(clip_len, -1, 2.5);
      // latch nose on the arm (-Y, snap engagement with lead-in)
      translate([0, -inner, clip_t]) nose(clip_len - bridge - 4, 1, 1.8);
    }
    // countersunk M3 through-holes into the tray bosses
    for (sx = [-1, 1])
      translate([sx*clip_screw_dx/2, 0, 0]) {
        translate([0, 0, -1]) cylinder(h = clip_t + 2, d = 3.4);
        translate([0, 0, clip_t - 1.8]) cylinder(h = 2.5, d1 = 3.4, d2 = 6.6);
      }
  }
}

// Hook nose bar: cross-section rises 45° from the channel floor to the lip
// seat, then slopes back up to the stock top (lead-in for the snap).
// dir = -1 noses toward -Y (from the +Y stock), +1 noses toward +Y.
module nose(len, dir, ov) {
  hook_h = lip_t + 2.2;
  translate([-len/2, 0, 0])
    rotate([90, 0, 90])
      linear_extrude(len)
        polygon([
          [-dir*2, 0],                                    // rooted 2 mm inside the stock
          [dir*min(ov, lip_t), min(ov, lip_t)],           // 45° chamfer
          [dir*ov, lip_t + 0.2],                          // lip seat tip
          [-dir*2, hook_h + 1.6],                         // lead-in slope back
        ]);
}

/* =========================== util =========================== */
module rrect(l, w, r) {
  offset(r) offset(-r) square([l, w], center = true);
}

/* =========================== emit =========================== */
if (part == "tray") tray();
else if (part == "clip") clip();
else {
  tray();
  // preview: clip flipped onto the tray back, rotated for the chosen mount
  translate([0, 0, -0.2]) mirror([0, 0, 1])
    rotate([0, 0, mount == "vertical" ? 90 : 0]) clip();
}

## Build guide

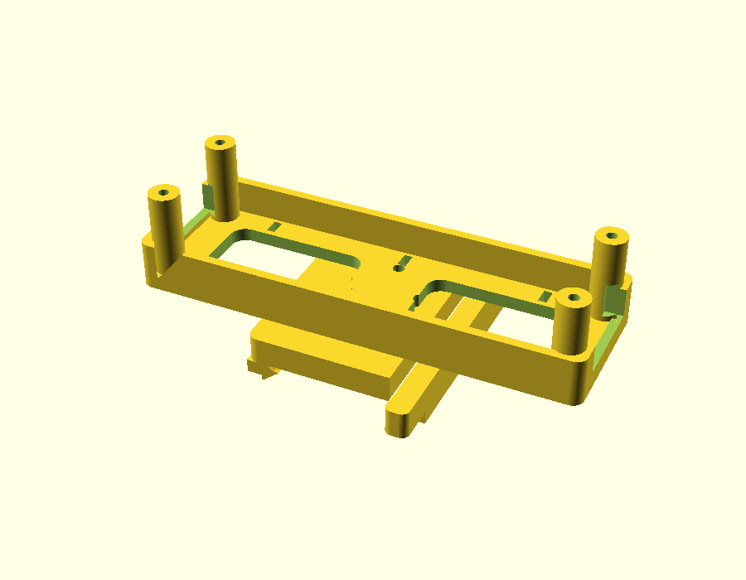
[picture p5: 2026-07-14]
hardware/preview-assembly.png

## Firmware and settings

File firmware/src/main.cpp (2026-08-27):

/**
 * freezerMon — mobile cooling unit monitor
 * Board: LilyGO T-A7608E-H (ESP32-WROVER-E + SIMCom A7608E-H, LTE Cat-4)
 *
 * Battery regime: wake (timer or door interrupt) -> read sensors -> evaluate
 *   alarm -> power modem, attach LTE, publish (+ flush offline buffer) ->
 *   modem off -> deep sleep. Sleep is the guaranteed terminal state: a task
 *   watchdog resets the chip if the network path wedges past the awake budget.
 *
 * Powered regime (external power present): deep sleep is a battery measure,
 *   so the device stays awake with the LTE/MQTT session up, polls the door
 *   every 250 ms (instant alerts) and reports every REPORT_INTERVAL_POWERED_S.
 *   Falls back to the battery regime when power is pulled or the link drops.
 */
#include "config.h"

#include <TinyGsmClient.h>
#include <PubSubClient.h>
#include <OneWire.h>
#include <DallasTemperature.h>
#include <ArduinoJson.h>
#include <driver/rtc_io.h>
#include <esp_sleep.h>
#include <esp_task_wdt.h>
#include <rom/rtc.h>             // rtc_get_reset_reason(core) — ROM-level reset forensics
#include <time.h>
#include <sys/time.h>          // gettimeofday: the RTC clock keeps running in deep sleep -> measured sleep length
#include <WiFi.h>
#include <WebServer.h>
#include <Preferences.h>         // NVS-backed device name (survives OTA; set via /setname)
#include <Update.h>
#include <freertos/FreeRTOS.h>
#include <freertos/semphr.h>    // modemLock: the dbgweb task and the main thread share one modem UART
#include "mbedtls/md.h"          // streaming SHA-256 (version-stable md_* API)
#include "mbedtls/pk.h"          // RSA-2048 signature verify
#include "ota_pubkey.h"          // OTA_PUBKEY_PEM — image-signing public key
#include "deviceid.h"            // deviceNameValid(), chipSeedName() — host-testable
#include "geo.h"                 // geoDistM() — movement detection, host-testable

#define FW_VERSION "2.97"   // verNewer() compares dotted INTEGER components: 2.10 > 2.9, and 2.7 < 2.68 — never drop a trailing digit

#define SerialMon Serial
#define SerialAT  Serial1

TinyGsm modem(SerialAT);
#ifdef USE_TLS
TinyGsmClientSecure netClient(modem);   // MQTT over TLS on mux 0
#else
TinyGsmClient netClient(modem);
#endif
// OTA/manifest fetches run over PLAIN HTTP on a second session (mux 1). The
// A76XX's second-TLS-session handshake was unreliable and cost a whole day of
// failed self-updates; a plain-TCP fetch (port 80 -> CCHOPEN client_type=1, no
// TLS handshake) sidesteps it. Access control is the unguessable token path;
// Update.begin/end validate the image, so a corrupt/truncated download fails
// safely. Non-secret payload, so no confidentiality need on the wire.
TinyGsmClient otaHttpClient(modem, 1);
PubSubClient mqtt(netClient);

OneWire oneWire(ONE_WIRE_PIN);
DallasTemperature probes(&oneWire);

// ---------- state that survives deep sleep ----------
struct Sample {
  uint32_t ageS;      // seconds since taken (incremented across sleeps)
  float    tCab;
  float    tAmb;
  uint16_t vbatMv;
  uint16_t vsolarMv;
  uint8_t  doorOpen;
  uint8_t  alarm;
  uint8_t  extPower;   // 1 = running on external power, 0 = on battery
};
#define BUF_MAX 24
RTC_DATA_ATTR Sample   rtcBuf[BUF_MAX];
RTC_DATA_ATTR uint8_t  rtcBufCount = 0;
RTC_DATA_ATTR uint8_t  consecutiveBreaches = 0;
RTC_DATA_ATTR uint8_t  alarmActive = 0;
RTC_DATA_ATTR uint32_t bootCount = 0;
RTC_DATA_ATTR uint8_t  reportsSinceGps = 0xFF;  // force fix on first boot
RTC_DATA_ATTR uint8_t  gnssZeroSatStreak = 0;   // GNSS-wedge watchdog: consecutive attempts tracking 0 sats
RTC_DATA_ATTR float    lastLat = 0, lastLon = 0; // most recent fix — movement baseline; NOT auto-published (see gpsFreshThisWake)
static bool gpsFreshThisWake = false;            // set only by a successful fix THIS wake — a published coordinate is a measurement, not a memory
static float lastFixHdop = 0;                    // quality of the fix behind lastLat/lastLon (published with it)
RTC_DATA_ATTR int64_t sleepStartUs = 0;          // RTC clock at deep-sleep entry; measured sleep length is applied at the next boot
RTC_DATA_ATTR uint8_t gpsMissStreak = 0;         // consecutive attempts with no gate-passing fix (indoors) — drives the backoff
// Outcome of the most recent GNSS attempt, published in EVERY frame as gps_last /
// gps_last_s / gps_last_hdop so a failed hunt is visible from the dashboard rather
// than indistinguishable from "did not try" (the frame goes out before the hunt,
// and only a success sends the follow-up). RTC: survives sleep, not brownouts.
//   0 = no attempt yet   1 = no fix in window   2 = fix seen but rejected by the gate   3 = fix published
//   4 = good fix obtained but the follow-up frame could not be sent (MQTT down after GNSS, even after a reconnect)
RTC_DATA_ATTR uint8_t  gpsLastStatus = 0;
RTC_DATA_ATTR uint16_t gpsLastSecs   = 0;
RTC_DATA_ATTR float    gpsLastHdop   = 0;         // best HDOP seen in that window (rejected or not)
RTC_DATA_ATTR uint8_t  gpsLastSats   = 0;         // most satellites in view at any poll of that window (fix or not)
RTC_DATA_ATTR char     gpsLastSvs[16] = "";       // per-constellation split at that moment, in sentence order (3 fields on this firmware: GPS/GLONASS/BeiDou)
RTC_DATA_ATTR char     gnssModeStr[12] = "";      // +CGNSSMODE? read-back after requesting all constellations
RTC_DATA_ATTR char     gnssModesStr[40] = "";     // +CGNSSMODE=? — the modes THIS modem firmware accepts
#ifndef GPS_MISS_BACKOFF_AFTER
#define GPS_MISS_BACKOFF_AFTER 3   // after this many straight misses, hunt only every GPS_MISS_BACKOFF_N wakes
#endif
#ifndef GPS_MISS_BACKOFF_N
#define GPS_MISS_BACKOFF_N     3   // (a success snaps back to GPS_EVERY_N_REPORTS)
#endif
static int   lastFixSats = 0;
#ifndef GNSS_MODE_STR
// +CGNSSMODE on THIS A7608E-H firmware accepts (1-3) (read back 2026-08-26 20:47Z; 15 was refused):
//   1 = GPS+GLONASS+Galileo+SBAS+QZSS (the default it was running)   2 = BeiDou only   3 = all of them
// The 3-field +CGNSSINFO count is GPS / GLONASS / BeiDou; Galileo is folded in, not reported separately.
#define GNSS_MODE_STR "3"
#endif
#ifndef GPS_ZERO_SAT_ABORT_S
#define GPS_ZERO_SAT_ABORT_S 30   // a healthy engine sees satellites within seconds; 0 in view after this long = wedged engine or no antenna -> stop wasting the window
#endif
#ifndef GPS_MAX_HDOP
#define GPS_MAX_HDOP   2.5f   // reject fixes with worse horizontal dilution (typical good fix: 0.8-1.5)
#endif
#ifndef GPS_REQUIRE_3D
#define GPS_REQUIRE_3D 1      // 2D fixes (no altitude solution) are also horizontally poor — reject
#endif
#ifndef GPS_SETTLE_S
#define GPS_SETTLE_S   10     // keep polling this long after the first good fix, publish the lowest-HDOP sample
#endif
static bool agpsLoaded = false;                  // ephemeris lives in GNSS-engine RAM: false after every modem power cycle
RTC_DATA_ATTR uint32_t rtcEpoch = 0;            // best-known epoch, aged across sleeps
RTC_DATA_ATTR uint32_t lastAgpsEpoch = 0;       // when AGPS ephemeris was last downloaded (validity ~hours)
// movement detection: position is anchored while parked; a fix > MOVE_ALARM_M
// from the anchor flags the unit as moving (alert + fast cadence + GPS every
// wake) until MOVE_STOP_CYCLES near-still fixes re-anchor it.
RTC_DATA_ATTR float    anchorLat = 0, anchorLon = 0;
RTC_DATA_ATTR uint8_t  movingActive = 0;        // in telemetry as `moving`; drives fast cadence
RTC_DATA_ATTR uint8_t  stillStreak = 0;         // consecutive near-still fixes while moving
RTC_DATA_ATTR uint8_t  moveAlertPending = 0;    // `moving` alert queued until MQTT is next up
RTC_DATA_ATTR uint8_t  tempAlertPending = 0;    // `temp_breach` alert queued — the latch can happen on a boot that dies before MQTT (double-boot pattern), so the edge is decoupled from the publish
static Sample lastSample; static bool lastSampleValid = false;   // main thread's most recent reading, for /status
static portMUX_TYPE sampleMux = portMUX_INITIALIZER_UNLOCKED;     // /status copies it on the console task
RTC_DATA_ATTR uint8_t  coldChargeActive = 0;    // cold-charge condition latched (one-shot alert + re-arm hysteresis)

uint32_t awakeStart = 0;

// powered-mode session state (external power -> no deep sleep needed)
bool     poweredSession = false;
uint8_t  lastDoor = 0;
uint8_t  prevAlarm = 0;
uint32_t lastReportMs = 0;

// ---------- LTE OTA state ----------
// A retained JSON on freezer/<id>/cmd declares the desired firmware:
//   {"ota_url":"https://host/fw/<token>/firmware.bin","ota_ver":"1.4"}
// The device acts only when ota_ver differs from FW_VERSION and power allows.
char          otaUrl[192] = "";
char          otaVer[16]  = "";
char          otaMd5[33]  = "";    // hex MD5 of the whole image; Update verifies it so a
                                   // corrupt assembly is never installed (empty = skip check)
volatile long otaSize     = 0;     // total image size; pieces are otaUrl.000, .001, …
volatile long otaSkip     = 4096;  // bytes to skip at the end of each piece (the modem
                                   // drops the last ~3072 of every cached response);
                                   // pieces overlap by this much so no data is lost.
volatile bool otaPending  = false;
volatile bool otaCheckRequested = false;   // /update "check online" — set by dbgweb task, consumed by main thread

static void logLine(const char *fmt, ...);   // defined below (ring-buffer logger)

// Strictly-newer version compare ("2.48" > "2.47"). Anti-rollback: OTA fires only
// for a newer version, so an attacker who can inject a command can't force a
// downgrade to an older (validly signed but vulnerable) build. Deliberate
// downgrades are done over UART.
static bool verNewer(const char *cand, const char *cur) {
  int c1 = 0, c2 = 0, r1 = 0, r2 = 0;
  if (sscanf(cand, "%d.%d", &c1, &c2) < 1) return false;
  sscanf(cur, "%d.%d", &r1, &r2);
  return (c1 != r1) ? (c1 > r1) : (c2 > r2);
}

// Reject an OTA URL that could break out of the AT+HTTPPARA="URL","..." line and
// inject AT commands (CR/LF or a stray quote) or overflow otaUrl[192]/purl[224].
// ArduinoJson decodes \r\n escapes into real control bytes, so this must run on the
// decoded string. Allow only a conservative printable URL charset.
static bool otaUrlSafe(const char *u) {
  size_t n = u ? strlen(u) : 0;
  if (n < 8 || n > 180) return false;
  if (strncmp(u, "http://", 7) != 0 && strncmp(u, "https://", 8) != 0) return false;
  for (size_t i = 0; i < n; i++) {
    unsigned char c = (unsigned char)u[i];
    if (c < 0x21 || c > 0x7e) return false;            // no controls/space/non-ASCII (blocks CR/LF)
    if (c == '"' || c == '\\') return false;           // no quote/backslash
  }
#ifdef OTA_MANIFEST_URL
  // Host pin: the device only ever legitimately fetches from the manifest's host. Without
  // this a cmd publisher could drive the fleet to GET any host:port reachable from the
  // cellular bearer (carrier-internal RFC1918 included) with /log as a status oracle.
  {
    const char *m = OTA_MANIFEST_URL; m += strncmp(m, "https://", 8) == 0 ? 8 : 7;
    const char *a = u + (strncmp(u, "https://", 8) == 0 ? 8 : 7);
    size_t ml = strcspn(m, "/:"), al = strcspn(a, "/:");
    if (ml == 0 || ml != al || strncasecmp(m, a, ml) != 0) return false;
  }
#endif
  return true;
}

static bool verStrictOk(const char *v) {           // ^[0-9]{1,3}\.[0-9]{1,3}$
  int a = 0, b = 0, dots = 0;
  for (const char *c = v; *c; c++) {
    if (*c == '.') { if (++dots > 1) return false; }
    else if (*c < '0' || *c > '9') return false;
    else if (dots == 0) { if (++a > 3) return false; } else { if (++b > 3) return false; }
  }
  return dots == 1 && a > 0 && b > 0;
}
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
void loop() {
  if (!poweredSession) goToSleep(REPORT_INTERVAL_S);    // safety net

  esp_task_wdt_reset();
  mqtt.loop();
  if (Update.isRunning()) {                             // OTA in progress — don't report or sleep
    // ... but never forever: a /update upload whose client vanished leaves Update
    // "running" with no completion handler, and this early return then starves
    // reporting indefinitely while feeding the watchdog (2026-08-27 10:05Z: first
    // powered session, silent for an hour). Abort after 5 min without completion.
    if (!updateRunningSinceMs) updateRunningSinceMs = millis();
    if (millis() - updateRunningSinceMs > 300000UL) {
      logLine("[ota] Update stuck running 5 min - aborting");
      Update.abort(); otaUploadActive = false; upBinDone = false; upSigLen = 0; upFwBlocked = false; updateRunningSinceMs = 0;
    } else { delay(5); return; }
  } else updateRunningSinceMs = 0;
  // Powered-regime liveness: if nothing has been published for 3 intervals, whatever
  // the cause, drop to a fresh cycle instead of idling on mains with no telemetry.
  if (millis() - lastReportMs > 3UL * REPORT_INTERVAL_POWERED_S * 1000UL + 60000UL) {
    logLine("[power] no report for %lus - forcing a fresh cycle", (millis() - lastReportMs) / 1000UL);
    goToSleep(REPORT_INTERVAL_FAST_S);
  }
#ifdef OTA_MANIFEST_URL
  if (otaCheckRequested) {
    checkOnlineUpdate();                                // own client on mux 1 — the MQTT session normally survives
    if (!otaPending && !mqtt.connected()) {             // restore only if it actually dropped
      char clientId[48];
      snprintf(clientId, sizeof(clientId), "freezermon-%s", deviceId);
      if (mqtt.connect(clientId, MQTT_USER, MQTT_PASS)) {
        char cmdTopic[64];
        snprintf(cmdTopic, sizeof(cmdTopic), "freezer/%s/cmd", deviceId);
        mqtt.subscribe(cmdTopic);
        snprintf(cmdTopic, sizeof(cmdTopic), "freezer/%s/telemetry", deviceId);
        mqtt.subscribe(cmdTopic);                       // echo subscription (delivery proof)
      } else {
        goToSleep(REPORT_INTERVAL_FAST_S);              // recover via a fresh cycle
      }
    }
  }
#endif
  if (otaPending) {                                     // powered = always allowed
    performOta(otaUrl, otaVer);                         // reboots on success
    otaPending = false;
    if (!mqtt.connected()) goToSleep(REPORT_INTERVAL_FAST_S);  // failed OTA dropped the link
  }
  delay(250);

  pinMode(DOOR_PIN, INPUT_PULLUP);
  uint8_t door = digitalRead(DOOR_PIN) == HIGH ? 1 : 0;
  bool doorChanged = door != lastDoor;
  // while moving, report at the fast cadence even on external power (live tracking)
  uint32_t poweredInterval = movingActive ? REPORT_INTERVAL_FAST_S : REPORT_INTERVAL_POWERED_S;
  bool reportDue = millis() - lastReportMs >= poweredInterval * 1000UL;
  if (!doorChanged && !reportDue) return;

  awakeStart = millis();                                // re-arm bounded-op budget
  Sample s;
  readSensors(s);
  evaluateAlarm(s);
  portENTER_CRITICAL(&sampleMux); lastSample = s; lastSampleValid = true; portEXIT_CRITICAL(&sampleMux);   // /status reads this copy
  gpsFreshThisWake = false;                             // powered loop never reboots — freshness is per report cycle
  // Echo accounting (2.95): the broker's copy of our retained frame arrives over LTE
  // through the modem's polled receive path and often lands well after a 3 s wait —
  // 2.93 judged it inside that window, never saw it, and escalated to a sleep cycle
  // every third report (13:06/13:15/13:23/13:32/13:40Z on 2026-08-27). Judge the
  // PREVIOUS cycle's echo here, with the whole interval to arrive, then reset.
  bool prevEcho = mqttEchoSeen;
  if (prevEcho) { clearPendingFix(); noEchoCycles = 0; }
  mqttEchoSeen = false; pendingFixSent = false;
  // GNSS-wedge recovery (powered regime only — battery self-heals via the
  // deep-sleep rail drop). A continuously-powered modem never loses the rail,
  // so when the watchdog reports the engine stuck, force a full power cycle
  // (the one thing that clears it) and re-establish the session.
  if (gnssZeroSatStreak >= GNSS_STUCK_CYCLES) {
    logLine("[gps] engine wedged %u cycles - full modem power cycle", gnssZeroSatStreak);
    gnssZeroSatStreak = 0;
    if (mqtt.connected()) mqtt.disconnect();
    modemPowerOn();                                     // true supply cut clears GNSS
    if (!modemConnect()) { goToSleep(REPORT_INTERVAL_FAST_S); }  // couldn't recover -> battery-style cycle
    char clientId[48];
    snprintf(clientId, sizeof(clientId), "freezermon-%s", deviceId);
    mqtt.setServer(MQTT_HOST, MQTT_PORT);
    if (mqtt.connect(clientId, MQTT_USER, MQTT_PASS)) {
      char cmdTopic[64];
      snprintf(cmdTopic, sizeof(cmdTopic), "freezer/%s/cmd", deviceId);
      mqtt.subscribe(cmdTopic);
      snprintf(cmdTopic, sizeof(cmdTopic), "freezer/%s/telemetry", deviceId);
      mqtt.subscribe(cmdTopic);                         // echo subscription (delivery proof)
    } else {
      goToSleep(REPORT_INTERVAL_FAST_S);
    }
    lastReportMs = millis();                            // skip this cycle's report; resume next loop
    return;
  }
  uint32_t now = networkEpoch();
  if (now) rtcEpoch = now; else now = rtcEpoch;
  int csq = modem.getSignalQuality();
  int16_t rssiDbm = (csq >= 0 && csq < 99) ? (int16_t)(-113 + 2 * csq) : -999;

  // Publish FIRST, GNSS LAST — same order as the battery path, for the same reason: the
  // A76XX GNSS engine shares the RF path and routinely drops the CCH session under the
  // MQTT client. 2.90/2.91 hunted before publishing on the held session; the first
  // powered report of the very first powered session failed exactly that way
  // (11:21Z 2026-08-27) and the unit fell back to sleep cycles every 3 minutes.
  if (!mqtt.connected()) poweredReconnect();            // session may have died since the last cycle
  // Same at-least-once rule as the battery path: a fix whose follow-up frame was not
  // echoed last cycle (3 of 11 on the first mains session, 2026-08-27) is re-sent as
  // a backfill point at its own timestamp before this cycle's frame; the echo of this
  // cycle's frame then clears it.
  if (mqtt.connected()) publishPendingFix();
  bool ok = mqtt.connected() &&
            publishSample(s, now, false, doorChanged ? "door" : "powered", rssiDbm);
  if (!ok && poweredReconnect())                        // one retry on a fresh session before giving up the regime
    ok = publishSample(s, now, false, doorChanged ? "door" : "powered", rssiDbm);
  if (ok) {                                             // give a fast echo a chance now; the real verdict is next cycle
    uint32_t tEcho = millis();
    while (millis() - tEcho < 3000UL && !mqttEchoSeen) { mqtt.loop(); delay(20); }
    if (mqttEchoSeen) { clearPendingFix(); noEchoCycles = 0; }
    else if (!prevEcho) {
      // Neither this cycle (so far) nor the whole previous interval brought an echo:
      // "connected" but the broker is not servicing the socket. Escalate — fresh
      // session after 2 silent cycles, full sleep/power cycle after 3.
      if (noEchoCycles < 255) noEchoCycles++;
      logLine("[mqtt] no echo of the powered frame (%u in a row) - fix kept for backfill", noEchoCycles);
      if (noEchoCycles >= 3) { bufferSample(s); goToSleep(REPORT_INTERVAL_FAST_S); }
      if (noEchoCycles >= 2) poweredReconnect();
    }
  }
  if (ok) {                                             // GNSS on the now-idle session; reconnect afterwards if it took the session down
    bool gotFix = maybeGps(GPS_FIX_TIMEOUT_S);
    if (!mqtt.connected()) poweredReconnect();
    if (gotFix && mqtt.connected()) {                   // same-ts follow-up carries the coordinates (upsert in InfluxDB)
      mqttEchoSeen = false;
      if (publishSample(s, now, false, doorChanged ? "door" : "powered", rssiDbm)) {
        uint32_t tEcho = millis();
        while (millis() - tEcho < 3000UL && !mqttEchoSeen) { mqtt.loop(); delay(20); }
        if (mqttEchoSeen) clearPendingFix();
      }
    }
    if (moveAlertPending && mqtt.connected()) {         // movement detected by that fix
      publishAlert(s, now, "moving");
      moveAlertPending = 0;
      saveMonState();
    }
  }
  if (doorChanged && s.doorOpen) publishAlert(s, now, "door_open");
  if (tempAlertPending) { publishAlert(s, now, "temp_breach"); tempAlertPending = 0; saveMonState(); }
  if (coldChargeCheck(s))        publishAlert(s, now, "cold_charge");
  prevAlarm = s.alarm;
  lastDoor = door;
  if (ok) lastReportMs = millis();                      // "last REPORT", not last cycle — the liveness guard keys off it
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

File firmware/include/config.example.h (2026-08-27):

// freezerMon device configuration
// Copy to config.h and fill in — config.h is gitignored, never commit credentials.
#pragma once

// ---- Identity ----
#define DEVICE_ID            "cooler-01"        // SEED default only — the live name lives in NVS and is
                                                //   set per-unit at runtime via the /setname console (survives OTA).
                                                //   Leave "" to auto-derive a unique cooler-<chipid> on first boot.

// ---- Cellular ----
#define APN                  "internet"          // Lebara DK: "internet" (verified live)
// Pin the network operator. Consumer MVNO SIMs (e.g. Lebara) may NEVER
// auto-select their home carrier — seen live: modem hunted foreign LTE and got
// denied while home coverage was available. 23866 = Telia-Telenor DK shared net.
// Comment out for automatic selection (IoT/roaming SIMs).
#define FORCE_PLMN           "23866"
#define GPRS_USER            ""
#define GPRS_PASS            ""
#define SIM_PIN              ""                  // leave empty if PIN lock disabled

// ---- MQTT ----
#define MQTT_HOST            "vps.example.com"
// Optional: broker IP, dialed first to bypass flaky carrier DNS on the modem.
// Requires a TLS front (e.g. Traefik HostSNI(`*`)) that routes SNI-less
// connections to the broker, and modem authmode=0 (no cert-CN check).
// Comment out to always use the hostname.
#define MQTT_HOST_IP         "203.0.113.10"
#define MQTT_PORT            8883                // TLS (default build env). 1883 only for LAN-only bring-up with the plain env
#define MQTT_USER            "freezer"
#define MQTT_PASS            "change-me"
// TLS: flash with `pio run -e t-a7608-tls -t upload` (defines USE_TLS) and set MQTT_PORT 8883

// ---- Reporting cadence ----
#define REPORT_INTERVAL_S       300              // normal (on battery): every 5 min
#define REPORT_INTERVAL_POWERED_S 120            // on external power: device stays AWAKE (no deep sleep) and reports at this cadence
#define REPORT_INTERVAL_FAST_S  60               // while alarm active or door open
#define GPS_EVERY_N_REPORTS     6                // wakes between GPS attempts (6 = ~30 min at the 5-min cadence). 0 = EVERY wake: movement is
                                                 // detected within one cadence instead of ~35 min, at roughly 2x the battery drain (~8 days parked, ~2 days in alarm)
#define GPS_MISS_BACKOFF_AFTER  3                // after this many consecutive no-fix attempts (indoors) ...
#define GPS_MISS_BACKOFF_N      3                // ... hunt only every Nth wake until a fix succeeds
#define GPS_FIX_TIMEOUT_S       90               // give up on fix after this (periodic wakes)
#define COLD_CHARGE_C           0.0f             // alert if external power is present while the battery probe (t_amb, strap to the cell) is below this — Li-ion must not charge below ~0C and the board's CN3065 TEMP protection is disabled (pin grounded)
#define MOVE_ALARM_M            150              // GPS displacement from the parked anchor that raises the `moving` alert (> GPS scatter)
#define MOVE_STOP_M             50               // consecutive fixes closer than this = standing still
#define MOVE_STOP_CYCLES        3                // still fixes needed to re-anchor + clear moving state
#define GPS_FIRST_BOOT_TIMEOUT_S 30              // shorter bounded window on a cold boot; if it fixes, the coords go out THIS wake in a follow-up frame
#define GPS_MAX_HDOP            2.5f             // fix quality gate: reject HDOP above this (good fix 0.8-1.5; first fixes are often 3-5 = +/-100 m)
#define GPS_REQUIRE_3D          1                // require a 3D fix (2D fixes are horizontally poor too)
#define GPS_SETTLE_S            10               // after the first good fix keep polling this long and publish the lowest-HDOP sample
#define AGPS_REFRESH_S          7200             // re-download AGPS ephemeris at most this often (~2 h) for fast cold fixes
// GNSS active antenna power. T-A7608/T-A7670: 127 = modem VDD_AUX rail
// (AT+CVAUXS=1). Without this the antenna is dead — zero satellites forever.
#define GPS_ANTENNA_POWER_PIN   127
#define GPS_ANTENNA_POWER_LEVEL 1
// GNSS-wedge watchdog: consecutive 0-satellite GPS attempts before forcing a
// full modem power cycle (the A76XX GNSS engine can hang until a supply cut).
#define GNSS_STUCK_CYCLES       3

// ---- Alarm thresholds ----
#define TEMP_ALARM_C            8.0f             // cabinet warmer than this = breach. Cooler: 8 (food-safety ceiling above a 4-6C band); freezer: -12. MUST sit above the unit's normal band or the alarm never clears (permanent 60s reporting = ~5x battery drain). Match the Grafana rule in infra/grafana/provisioning/alerting/alerts.yml
#define ALARM_CONSECUTIVE       3                // consecutive breaches before alert
#define BATT_LOW_MV             3400
#define EXT_POWER_MIN_MV        4400             // VIN/solar ADC above this = external power present
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

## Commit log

2026-07-14 freezerMon — cellular cold-chain monitor (LilyGO T-A7608E-H)
    ESP32 + SIMCom A7608 LTE Cat-4 device that reports cabinet temperature,
    door, battery/power and GPS over LTE→MQTT to a self-hosted stack
    (Mosquitto/Telegraf/InfluxDB/Grafana).
    Highlights:
    - Reliable ~900KB firmware self-update over LTE (piece-split + tail-skip
    around the A7608 HTTP quirks + per-piece retry) — see docs/OTA-INVESTIGATION.md
    - Signed OTA: RSA-2048/SHA-256 image signature verified on-device with mbedTLS,
    version bound into the signature for anti-rollback, signed local /update
    — see docs/HARDENING.md
    - Assisted GNSS (AT+CAGPS) for fast cold fixes; deep-sleep power budget
    - Offline buffering, GNSS-wedge wa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
    [DinClipTS35.stl, DinRailMount.scad, TrayT-A7608.stl]
2026-07-14 add MIT LICENSE + THIRD-PARTY-NOTICES
    License freezerMon's own code under MIT. Document dependency licenses,
    flagging TinyGSM (LGPL-3.0) and the Arduino-ESP32 core (LGPL-2.1) — weak
    copyleft, satisfied by the public, rebuildable source. Grafana is AGPL-3.0
    but used as a stock service (no obligation).
2026-07-14 docs: bring README current — signed/split-piece/anti-rollback OTA, security model, assisted GNSS
    The OTA + Security sections still described the old unsigned TLS-streaming
    update. Rewrite them for the signed, version-bound, split-piece plain-HTTP OTA
    and signed /update; link docs/HARDENING.md + docs/OTA-INVESTIGATION.md; add the
    signing-key setup; note assisted-GNSS data cost; fix the debug-AP window default.
2026-07-14 docs: add technical 'OTA download internals' section
    Explain the piece-split download and verification: why the A7608 can't stream a
    ~900KB response (57KB cache, 3072-byte tail-drop, no 206, CCH stall), the
    overlapping-piece split (PIECE/OVERLAP/STEP) + deliverable-prefix read that dodges
    the tail-drop and tiles with no gap, read-from-0 + retry, and the MD5 + version-bound
    RSA-2048/SHA-256 signature gate before Update.end (with anti-rollback).
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2026-07-14 grafana: fix blank Battery/Signal graphs + auto-discover devices
    The Battery voltage and Signal strength timeseries panels rendered completely
    blank (no axes/line) despite the queries returning data and the matching stat
    tiles working — a corrupt property in their fieldConfig/options. Rebuilt both
    from the working Temperature panel (same render config; own query/title/unit/
    label). Also restored the `device` variable to a query type
    (schema.tagValues) so it auto-discovers any device tag. Verified rendering in
    the logged-in dashboard via screenshots.
2026-07-14 firmware: runtime device name via NVS + /setname console (fw 2.54)
    DEVICE_ID was compile-time baked into the binary, so OTAing one image to a
    fleet would make every unit publish as the same device. Resolve the name at
    boot from NVS instead (survives OTA — only the app partition is rewritten):
    stored name wins, else seed from config.h DEVICE_ID, else a unique
    cooler-<chipid> from the efuse MAC. Add a /setname console endpoint to name a
    unit in the field; names restricted to [a-z0-9-] (blocks MQTT topic injection).
    Existing unit migrates to the same cooler-01. Docs + config template updated.
    [config.example.h, main.cpp]
2026-07-14 firmware: bounded cold-boot GPS + same-wake follow-up frame (fw 2.55)
    On a cold boot (battery), run GNSS with a shorter GPS_FIRST_BOOT_TIMEOUT_S (30s)
    window instead of the full 90s, and if a fix lands and the MQTT session survived
    GNSS, publish a follow-up frame carrying the coords THIS wake (same ts -> InfluxDB
    upserts location onto the point) rather than waiting for the next wake. maybeGps()
    now takes a timeout + returns whether it fixed. Primary publish path unchanged
    (GPS still after it; follow-up is best-effort, guarded by published && connected)
    so no new modem-wedge risk. Net cold-boot GNSS power drops (30s vs 90s).
    [config.example.h, main.cpp]
2026-07-14 firmware: address independent-review findings (fw 2.56)
    Fixes from the SSDLC §7 gate on the 2.54/2.55 diff (issue #5 broker ACL deferred
    to infra):
    - #1 HIGH: chip-derived default name used the shared Espressif OUI bytes
    (mac & 0xFFFFFF) -> every un-named fleet unit collided on one name. Now derives
    from the NIC-unique octets ((mac>>24)&0xFFFFFF).
    - #2 HIGH: deviceNameValid allowed 30-char names but freezermon-<name> then
    exceeded the 32-char SSID limit -> softAP() failed silently -> debug AP + the
    only field-rename path stranded. Cap names at 21; also check softAP() and fall
    back to a fixed SSID.
    - #3 MED: /setname was an unauthenticated GET state-change (CSRF + reboot DoS).
    No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
    [main.cpp]
2026-07-14 docs: fix host_test path in deviceid.h comment (review nit)
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2026-07-14 firmware: GPS-based movement alarm + live tracking cadence (fw 2.58)
    The board has no accelerometer, so detect movement by GPS displacement from a
    parked anchor: a fix > MOVE_ALARM_M (150m, above measured ~21m bench scatter)
    raises a one-shot 'moving' alert and switches to fast reporting (60s) with a
    GPS fix EVERY wake (battery + powered regimes) so the map tracks the unit live;
    MOVE_STOP_CYCLES near-still fixes re-anchor and restore normal cadence. Adds
    'moving' to telemetry + /status, alert queued in RTC until MQTT is next up.
    geoDistM in include/geo.h (equirectangular) with host tests.
    [config.example.h, main.cpp]
2026-07-15 docs: 18650 voltage ladder + brownout diagnosis/mitigations (bulk cap, cold-cell guidance)
2026-07-15 firmware: skip debug AP on brownout-recovery boots (fw 2.59)
    A brownout reset enters the heaviest possible cycle (2-min WiFi AP + AGPS +
    forced GPS hunt + LTE attach + double publish), which can re-trigger the sag
    that caused the reset - a self-sustaining reboot loop, observed live (boot:1/
    power_on every cycle for an hour on a healthy-resting-voltage cell). Minimal
    first mitigation: shed the WiFi AP load on reset=BROWNOUT cold boots; healthy
    cold boots (power-on/RST) still get the console.
    [main.cpp]
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2026-07-15 firmware: reset forensics for the no-sleep sw-reset loop (fw 2.61)
    Since USB power was removed the device software-resets at every sleep attempt
    instead of deep-sleeping (reset=sw, boot:1, ~6min cycles, RTC wiped each time -
    RTC_DATA_ATTR only survives deep-sleep wakes). goToSleep is unchanged since the
    known-good 2.53, so instrument instead of guess: NVS phase breadcrumbs (survive
    any reset) record how far each cycle got (1=setup .. 5=deep-sleep entry), ROM
    per-core reset reasons (rom/rtc.h) distinguish esp_restart from a panic whose
    RTC-stored PANIC hint was lost, and telemetry gains rst + ph fields for remote
    diagnosis.
    [main.cpp]
2026-07-15 firmware: shed GNSS on brownout-recovery boots - breaks the reboot loop (fw 2.62)
    2.61 forensics named the killer: every cycle died at ph=1 (mid-GNSS, after a
    clean publish) with rst=BROWNOUT. Mechanism: brownout wipes RTC -> next boot
    FORCES GPS+AGPS (cadence counter reinitialized) -> GNSS+RF load browns the
    cell out again -> self-sustaining. The earlier reset=sw reading was the OTA
    install reboot, a red herring. Fix: on a BROWNOUT boot skip AGPS/GNSS and the
    follow-up frame for that cycle (AP already shed since 2.59), set the GPS
    counter to retry on the normal cadence, publish light, reach deep sleep.
    README brownout section updated.
    [main.cpp]
2026-07-15 docs: KSD9700 thermal switch as the recommended cold-charge cutoff
    Restructure the charging-protection section: Option A (recommended, no board
    soldering) = KSD9700 bimetal switch spliced into the 5V charge-input lead,
    bonded to the cell - autonomous, firmware-independent, battery keeps the
    monitor alive while cold. Explicit warning against placing it between battery
    and board (kills the monitor when cold + series resistance in the 2A burst
    path = the brownout loop). CN3065 TEMP pin-lift demoted to Option B.
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2026-07-15 firmware: modem power-on precharge + inrush-aware GNSS shed (fw 2.63)
    Forensics revision: the 'loop' was a DOUBLE BOOT per wake, not a no-sleep loop.
    Cadence is a metronomic 300s sleep + ~22s work; every wake's FIRST modem
    power-on inrush browns out the marginal cell/holder (dies at ph=1), the
    reboot's second attempt survives on the precharged caps and publishes. Fixes:
    (1) modemPowerOn precharge double-tap - a 150ms first tap charges the bulk
    caps, bounding the final enable's inrush, emulating exactly why the second
    boot always survived; (2) new 'attached' phase marker (ph=2) disambiguates
    wake-inrush deaths (ph=1/6) from RF-load deaths (ph=2-5), and GNSS is shed
    only for the latter - resto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
    [main.cpp]
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2026-07-15 firmware: NVS-mirror the alarm/movement/AGPS state (fw 2.64)
    On a marginal supply the wake-inrush brownout wipes RTC every cycle, which
    silently killed the safety functions: the temp alarm could never accumulate
    its 3 consecutive breaches, the movement anchor re-anchored every boot, and
    AGPS re-downloaded every wake. Mirror that state in NVS - written through on
    change (NVS skips unchanged values, so no flash wear), restored on any boot
    that wiped RTC (deep-sleep wakes keep RTC live). Breach counter now caps at
    ALARM_CONSECUTIVE (counting past the latch added nothing and would cost a
    write per breaching wake). All alarms now work even in double-boot mode;
    the hardware inrush fixes become eff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
    [main.cpp]
2026-07-15 docs: heater = 12V films derated at 5V, burn-proof by physics
    Owner reviews measure ~180C on these PI films at rated voltage, and the
    cell-mounted KSD controls duty cycle, not film surface temperature - so a
    rated-voltage film runs full power (hotspot >100C possible) during a cold
    start. Recommend two 12V 7W films in parallel on the 5V rail (~2.4W total,
    ~17% of rating each, ~25-30K max rise even free-standing). Rated-voltage
    films demoted to 'if you must' with spreader-bonding + on-film fuse rules;
    explicit warning never to move the heater branch to a vehicle 12V rail.
    Parts list updated.
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2026-07-15 firmware: queued temp_breach alert + persist last-known position (fw 2.65)
    Two double-boot interplay fixes found live on 2.64:
    - The alarm latch can happen on the boot that dies at modem power-on; the
    publishing boot then loads alarmActive=1 from NVS and its edge test
    swallows the alert (alarm:1 in telemetry, alert topic silent). Queue a
    NVS-mirrored tempAlertPending at the transition inside evaluateAlarm and
    publish it from whichever boot next has MQTT - same pattern as the
    movement alert.
    - lastLat/lastLon now NVS-persisted (written only on a new fix), so frames
    carry the last-known position through brownout RTC wipes when no fresh
    fix is available (e.g. indoors) instead of o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
    [main.cpp]
2026-07-15 firmware: coords only when a fix was obtained THIS wake (fw 2.66)
    Peter's rule: a published coordinate must be a measurement, not a memory -
    stale coords mask 'cannot get a fix', and absence of data IS the signal.
    Reverts 2.65's NVS position persistence and goes stricter than the original
    behavior (which replayed the last fix on non-GPS wakes): publishSample gates
    lat/lon on a per-wake gpsFreshThisWake flag set only by a successful fix
    (reset per report cycle in the powered loop). Side benefit: backfilled
    offline frames no longer inherit the current wake's position. Last-known
    location lives in the DB history where it belongs. README table updated.
    [main.cpp]
2026-07-15 docs: fix the charge-gate setpoint - the protection edge is the RE-OPENING
    The Option A note recommended an NO ~+5C disc 'for margin' - wrong edge: KSD
    discs re-open 10-20K BELOW their action point, so a +5C part keeps charging
    enabled down to roughly -5..-15C, violating the 0C hard limit. Correct rule:
    T_action - dT_return >= 0C -> ~15C action minimum with typical hysteresis
    (verify the return differential on the purchased part's datasheet). Option A
    diagram + part note and Option C's setpoint rationale updated; the NO 15C
    choice is required, not stock-pragmatism.
2026-07-15 firmware: AGPS validity tracks modem power cycles, not wall time (fw 2.67)
    2.64's NVS-persisted AGPS age was a false optimization that killed GPS on
    battery, caught by Peter ('the unit hasn't moved since yesterday' yet zero
    fixes): +CAGPS loads ephemeris into the GNSS engine's RAM, which dies with
    the modem rail on every deep sleep. The persisted timestamp skipped the
    re-download -> unassisted cold start in a 30s window -> no fix, every wake
    (last fix 10:42, right as the cache took effect). Fix: agpsLoaded flag
    cleared by modemPowerOn() (rail cycled = assistance gone), set on CAGPS
    success; the 2h wall-clock cap now only throttles the powered regime where
    the modem stays up. Battery behavior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
    [main.cpp]
2026-07-15 docs: final state - marginal-supply resilience summary + full telemetry field table
    Replace the outdated blanket-shed description with the actual shipped design
    (2.59-2.67): phase breadcrumbs, AP shed on brownout boots, RF-load-aware GNSS
    shed, NVS-mirrored alarm/movement/alert state, AGPS per modem power cycle -
    fully functional on a supply that browns out every wake. Telemetry table
    gains wake/rst/ph/fw rows.
2026-08-26 docs: ext_power sensing on GPIO34 - V1.0 boards lack the solar divider; 100k/100k fix + 2.5 V bench test
2026-08-26 firmware: publish timer-wake GPS fixes via the follow-up frame (fw 2.68)
    Since 2.66 coords ship only when a fix was obtained THIS wake, and the
    follow-up frame that carries them was gated on coldBoot - so every fix
    from a periodic timer wake was silently dropped. Unnoticed because the
    July verification unit was brownout-looping: every cycle was a cold boot.
    Any wake with a fix now sends the same-ts follow-up frame.
    [main.cpp]
2026-08-26 security: close the 2026-08-26 independent-review HIGHs (fw 2.69 + broker ACLs)
    Firmware (2.69):
    - Modem UART owned by a recursive FreeRTOS mutex; console handlers try-take
    and answer "busy". /lte no longer clears the main thread's claim, /sms is
    guarded like /lte, modemBusy is written by the main thread only and nested
    OTA paths restore it instead of clearing it.
    - /log ring is a fixed char[96][160] under a spinlock (was String[] — UAF
    between logLine on both tasks and the /log reader).
    - performOta is time-boxed (MAX_OTA_MS, 15 min) and remembers failures in NVS
    (OTA_MAX_FAILS = 3 per version): a retained cmd pointing at a broken image
    can no longer keep the unit awake every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
    [main.cpp]
2026-08-26 firmware: GPS fix quality gate - 3D + HDOP <= 2.5, settle dwell, hdop/sats in telemetry (fw 2.70)
    readGnssFix() took the first sentence with a lat/lon regardless of quality; on
    the bench 40 first-fixes spread 196 m N-S (median 27 m, p90 81 m, max 111 m
    from centroid) against a 150 m moving-alert threshold measured from whichever
    fix happened to become the anchor. Now a fix must be 3D with HDOP <= GPS_MAX_HDOP,
    polling continues GPS_SETTLE_S after the first good fix and the lowest-HDOP sample
    is published; a window with no good fix publishes no coordinate. hdop + sats ride
    along with lat/lon so scatter is diagnosable from Grafana. Field order verified
    against the TinyGSM fork's +CGNSSINFO par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
    [config.example.h, main.cpp]
2026-08-26 grafana: device-state row (alarm, movement, wake, reset, fw, fix quality) + state timeline; rst/ph/moving/hdop/sats in the frames table
2026-08-26 firmware: GPS every wake option (GPS_EVERY_N_REPORTS 0), miss backoff, cold-boot window extends while a fix is converging (fw 2.71)
    Movement is GPS-inferred, so the attempt cadence is the detection latency
    (~35 min parked at N=6). N=0 attempts every wake: one cadence to detect a
    move, at ~2x the drain (~8 days parked / ~2 days in alarm on a 2600 mAh cell)
    - accepted for this deployment. Guard: after GPS_MISS_BACKOFF_AFTER straight
    misses the unit hunts every GPS_MISS_BACKOFF_N wakes until a fix succeeds.
    Cold-boot 30 s windows now extend to GPS_FIX_TIMEOUT_S when a fix exists but
    still fails the HDOP gate, instead of discarding a converging fix.
    [config.example.h, main.cpp]
2026-08-26 firmware: gps_last/gps_last_s/gps_last_hdop breadcrumbs in every frame (fw 2.72)
    The frame goes out before the GNSS hunt and only a success sends the follow-up,
    so a failed or gate-rejected hunt was indistinguishable from no attempt. Every
    frame now carries the outcome of the most recent attempt: 1 = no fix, 2 = fix
    seen but rejected (best HDOP included), 3 = published; plus seconds spent.
    [main.cpp]
2026-08-26 firmware: crash forensics - RTC_NOINIT log tail published as crash_log after WDT/PANIC resets, rr0/rr1 in non-sleep boots (fw 2.73)
    Three INT_WDT resets at ph=1 since 2.69 (0 in the preceding 3.5 h) alongside a
    brownout loop; cannot be attributed from telemetry. The last CRASH_LINES log
    lines now survive software/WDT/panic resets in RTC_NOINIT memory and ship in
    the next frame, so the dying line is visible remotely.
    [main.cpp]
2026-08-26 grafana: frames table shows every field (drop keep list), ordered columns, GPS/reset colouring
2026-08-26 firmware: shed GNSS after BROWNOUT_SHED_AFTER consecutive brownout boots, bo_streak field (fw 2.74)
    With GPS on every wake a brownout-looping unit spends up to 100 s per cycle in
    GNSS + RF and browns out again at the next inrush even on the charger
    (20:00-20:03Z, cell at 4.2 V). Like the AP shed, the recovery cycle now drops
    GNSS from the 3rd consecutive brownout so the cycle is light enough for the
    supply to settle; the first clean deep-sleep wake resets the streak.
    [main.cpp]
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2026-08-26 firmware: reconnect MQTT for the fix frame when GNSS dropped the session; gps_last=4 marks a fix that could not be sent (fw 2.78)
    [main.cpp]
2026-08-26 firmware: brownout streak resets only after a non-brownout wake publishes, so the GNSS shed engages in the double-boot loop (fw 2.80)
    [main.cpp]
2026-08-26 firmware: persist good fixes to NVS and backfill them (own ts, gps_backfill=1) until one lands; probe +CGNSSMODE mode,1 syntax (fw 2.82)
    Four fixes tonight were obtained and never reached the DB - a stale CCH session
    reports connected and swallows the publish. A good fix now survives in NVS and
    is re-published as a backfilled point on following wakes until a delivery
    coincides with a wake whose own frame landed.
    [main.cpp]
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2026-08-26 firmware: pending fix cleared only after a two-way-verified session (backfill sent + retained cmd received); never on publish() alone (fw 2.84)
    publish() returns true into dead CCH sockets. 2.82's clear-on-publish lost the
    21:25Z and 21:29Z fixes exactly like the pre-backfill era. The NVS copy now
    survives until a later wake both sends the backfill AND sees inbound MQTT
    traffic - at-least-once delivery; duplicate points share a ts and upsert.
    [main.cpp]
2026-08-26 firmware: frame payload 384 -> 768 bytes, MQTT buffer 1024, refuse truncated frames loudly (fw 2.85)
    serializeJson truncates silently at the buffer and returns bytes written; the
    2.7x diagnostic fields pushed coordinate frames past 384 bytes, so every fix
    frame reached Telegraf as invalid JSON and was dropped at ingest. This - not
    dead sockets - is where tonight's fixes went. measureJson guard makes any
    future overflow loud and refuses to publish clipped JSON.
    [main.cpp]
2026-08-26 firmware: backfill frame must not carry a 'device' field - it collides with the topic tag and breaks every Flux pivot (fw 2.86)
    [main.cpp]
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2026-08-27 fw 2.87 + infra hygiene: independent-review round 4 (opencode GPT-5.5 + Kimi K3 + Silas) folded in
    Firmware:
    - pending-fix clear is now delivery-verified by the broker echoing our own
    retained frame (subscribe to freezer/<id>/telemetry), not by an optional
    cmd downlink (which is absent on a fleet with no retained OTA -> a fix
    republished forever). Pending fix is one NVS blob, written only on change.
    - OTA failure memory: global consecutive counter (OTA_MAX_FAILS_TOTAL) on top
    of the per-version one - cycling ota_ver labels can no longer evade it;
    reset only when FW_VERSION changes (a real install). ota_ver validated
    strictly at the callback so it can never carry junk into log lin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
    [config.example.h, main.cpp]
2026-08-27 firmware: supply-sag instrumentation through modem power-on (vbat_rest/min/sag_ms/sag_at) to size the brownout fix (fw 2.88)
    [main.cpp]
2026-08-27 firmware: sag sampler at ~10 kHz for 60 ms after each power-on edge, vbat_sag_n spike-persistence count (fw 2.89)
    [main.cpp]
2026-08-27 grafana: location map shows the fix track (route + dots, time-ordered) plus the latest fix
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2026-08-27 firmware: powered-regime parity - clock sync before the hunt, echo-verified pending-fix clear after the powered frame, echo re-subscribe on loop() reconnects (fw 2.90)
    [main.cpp]
2026-08-27 firmware: powered-regime self-heal - bounded Update.isRunning guard, 3-interval liveness fallback to a fresh cycle, no debug AP right after a WDT/PANIC reset (fw 2.91)
    [main.cpp]
2026-08-27 firmware: powered loop publishes first and hunts last, reconnects the MQTT session after GNSS instead of dropping to sleep, follow-up frame carries the fix (fw 2.92)
    [main.cpp]
2026-08-27 firmware: powered regime treats missing broker echoes as a connectivity failure - reconnect after 2, full cycle after 3 (fw 2.93)
    [main.cpp]
2026-08-27 firmware: powered loop backfills an un-echoed fix before the next frame (at-least-once on mains too) (fw 2.94)
    [main.cpp]
2026-08-27 alerting: temperature/battery rules use last() over 30 min with NoData/Error -> OK (silence belongs to the offline rule), values in the messages, offline confirmation 5 min
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2026-08-27 alerting: YAML comment had leaked into the temperature rule's Flux text (# is not a Flux comment)
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2026-08-27 firmware: judge the broker echo over the whole powered interval, not a 3 s window - the 2.93 escalation forced a sleep cycle every third report (fw 2.95)
    [main.cpp]
2026-08-27 acl: devices may read their own telemetry topic - the broker echo used as delivery proof was silently denied (forced a sleep cycle every third powered report); comments on their own lines, Mosquitto 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
2026-08-27 alerting: 'Cabinet probe missing' rule - frames arriving but no cabinet temperature for 15 min
2026-08-27 fw 2.96 + relay hardening (review round 5, security): echo must carry this cycle's ts (a stray retained frame or another credential holder is no longer delivery proof), /status copies the cached samp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
    [main.cpp]
2026-08-27 fw 2.97 (review round 5, correctness): echo matched on a per-frame seq as the FIRST key (same-ts follow-ups and quoted JSON in crash_log can no longer pass as the echo; works with an unsynced clock),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
    [main.cpp]
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2026-09-05 alerting: mute a unit that has been silent for more than a day
    Every rule now carries a last_report_age_s annotation (seconds since the unit's
    newest reading, re-rendered each evaluation; the probe rule gains the D/E age
    queries the others already had). The relay drops any message - alarm, 4-hourly
    reminder, or "OK again" - whose age exceeds MUTE_AFTER_SILENT_S (default 86400,
    0 disables), and anything firing with NoData. Grafana's state is untouched, so no
    timeout-induced resolved notification can reach the phone; a fresh reading clears
    the alarm the normal way. Relay unit tests added (bun test); env threaded through
    compose, .env.example and README.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
